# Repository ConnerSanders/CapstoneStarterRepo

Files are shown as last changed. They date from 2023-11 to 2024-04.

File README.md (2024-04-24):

# Pulse Inverted Electrolyzer

## Executive Summary

 The Pulse Inverted Electrolyzer primary goal is to boost the efficiency of the standard constant current electrolysis machine. A Standard Electrolysis system takes in constant current and turns an electrolytic solution into gasses from said solution. The  Pulse Inverted Electrolyzer will boost efficiencies in two ways. One will be by pulsing the current given to the electrodes, and the other by using constant magnetic fields to redirect ions back to the electrodes. By pulsing the current in an electrolyzer it takes advantage of two ideas happening inside the water of the system. When first fired on the electrodes will gain electrons around, and prevent current from passing through. By pulsing the current the system allows for this layer to disperse to make for more current to flow through the electrolytic solution. Also by pulsing the current, we will be able to send a burst of energy through the system instead of the constant current normally supplied. The other way the system will boost efficiency will be by using magnets placed around the housing of the cell. This will basically push the electrons closer to the electrodes and further away from the cell walls. The system will also include a way to read the power the pulse inverter will be drawing and the amount of gas being outputted, to then calculate the efficiency of the energy of the system's output versus its input. 

## Capabilities
The system will be divided into multiple systems that each have several expectations. The controller system should calculate the energy efficiency based on the flow rate of the gas output and the current draw of the pulse inverter. The safety system should any failed state go to a shutoff state. There will be a bypass for the user to be able to light the gas at the output of the gas system. The water system should automatically refill the cell with water whenever the system is too low.

## Salient Outcomes

While we did connect a pulse inverter to the cell, there were many issues with the pulse inverter tied to the resistance. The group was able to adjust to a lot of unknowns such as the pulse inverter's resistance and adapted as best as they could. Another Big outcome was the fact we had gas production from a pulsed current, as it is not common practice and with more time we could figure the best parameter of the pulse inverter to boost gas production.

## Project Demonstration & Images
[Video Demonstration](https://www.youtube.com/watch?v=DhT7RktQMQU)
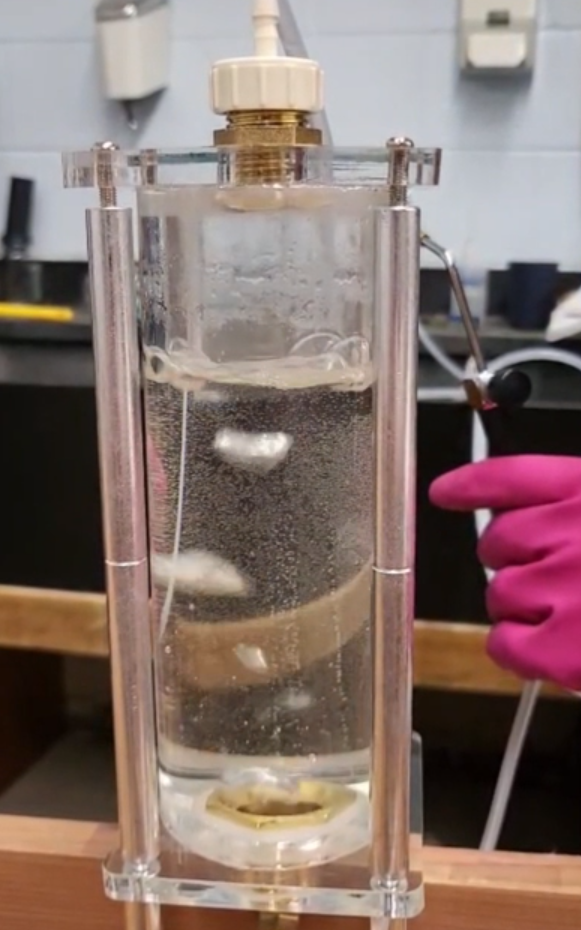
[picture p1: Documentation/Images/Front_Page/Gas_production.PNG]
<br> 
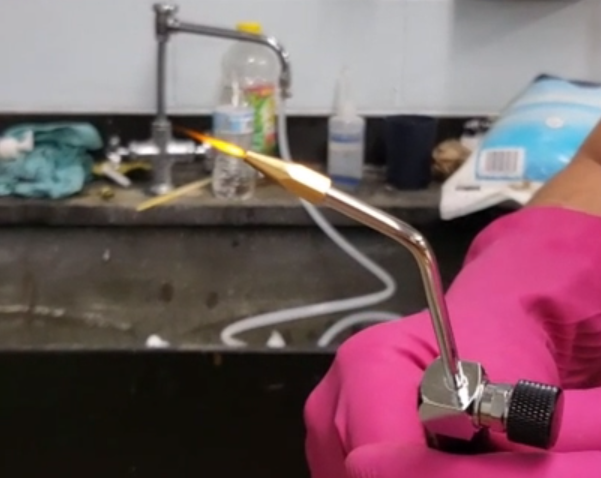
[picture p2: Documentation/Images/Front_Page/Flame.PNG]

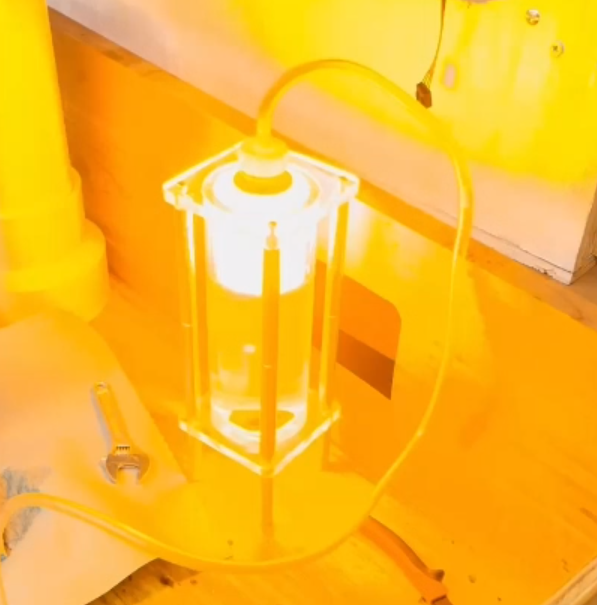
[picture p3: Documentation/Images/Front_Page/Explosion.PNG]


## About Us

### Team

**Brennan Angus**

**Matthew Beausoleil** is an Electrical Engineering student at Tennessee Technological University with a minor in Computer Science. Matthew's interests are in digital system design, telecommunications, and signal processing. Matthews's main focus in the project is the design of the water system, and ensuring that it automatically refills the water when senses it is not high enough.

**Jacob Cooper** is a Computer Engineering student at Tennessee Technological University. Jacob's interests are Circuits and Digital Based Programming. Jacob's main focus in the project is the design of the gas system and making sure there is correct ventilation and gas processing in order to create an output flame.

**Wyatt Groves** is an Electrical Engineering student at Tennessee Technological University. Wyatt's interests are Telecommunication and Signal Processing. Wyatt's main focus in the project is the design of the power system and ensuring all components receive the proper amounts of power. 

**Austin Jerrolds** is a Computer Engineering student at Tennessee Technological University. Austin's interests are Embedded Systems, Digital System Design, and software development. Austin's main focus in the project is the controller system which is responsible for the efficiency computations to measure the project's success. 

**Conner Sanders** is a Computer Engineering student at Tennessee Technological University. Conner's interests are embedded and Digital Systems. Conner also has some experience with controls and pneumatics. Conner's main focus in the project is the safety system, which cuts off power if the electrolyzer becomes unsafe.

### Faculty Supervisor
[Charles Van Neste, Phd](https://www.tntech.edu/directory/engineering/faculty/charles-van-neste.php) is an Assistant Professor at Tennessee Tech University. He received his Bachelor's, Master's, and Doctorate at Tennessee Technological University. 

### Stakeholders
The customer for the project is Dr. Van Neste for research he wishes to pursue in making a residential electrolyzer for the uses of hydrogen-powered cars. The project will be using technology develop by Dr Van Neste to see the impact it would have on the overall efficiency of the system.  

### Recognitions

The team would like to thank the ECE Department for any assistance needed in the early stages of design. We would especially like to thank **Jesse Roberts** for helping the team when Dr. Van Neste was busy with other work. 

## Repo Organization

### [Reports](/Reports)

The [Project Proposal](/Reports/Proposal/Project_Proposal-V2.pdf) report addresses key questions about the project. It states exactly what the problem is and what the solution plans to achieve. 

The [Conceptual Design and Planning](/Reports/Conceptual%20Design/Conceptual_DesignV2.pdf) report provides all specifications and constraints the project must follow. This includes standards and regulations that must be followed.

The [Experimentation](/Reports/Experimentation/Experimentation.md) report shows the experimentation done by the team to verify the project's constraints and measures of success.

The [Poster](/Reports/Poster/Capstone_Final_Presentation_Poster.pdf) is a visual summary of the project that is presented at the Senior Design Expo.

The [Final Presentation](/Reports/Final%20Presentation/Capstone%20Final%20Presentation.pdf) includes the final report/presentation done by the team to summarize the project's progress.

The [Lessons Learned](/Reports/Lessons%20Learned/Lessons%20Learned.md) files show all lessons learned throughout the process. It includes lessons in team communication, project management, and technical knowledge.

### [Documentation](/Documentation)

All documentation is included in the above folder. Folders for the files including schematics and images are included in their respective folders. All files related to a specific signoff are then in a subfolder labelled appropriately.

Documentation includes all schematics, images, models, and designs used in the project. 

[Signoffs](/Documentation/Ss) folder houses all approved detail designs. These designs are for each subsystem and show all constraints. The signoffs should convince the reader that all constraints are met as well as link to all other relevant documentation in their respective folders. These signoffs should also link any relevant software.

The [Meeting Minutes](/Documentation/Meeting%20Minutes) folder contains dated minutes for all team meetings. This allows the reader to analyze current and previous progress in a time-based manner. 

### Software
All software will be located in this directory. For each specific problem or system, a folder will be created that contains all relevant code along with a readme that explains the installation, compiling, and execution of the code.

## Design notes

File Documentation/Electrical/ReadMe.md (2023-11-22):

## Electrical Schematics Included 
1. Electrolysis System Pulse Inverter
2. Controller System Sensors and Microcontroller
3. Water System Valve
4. Power System Wiring
5. Safety System Wiring

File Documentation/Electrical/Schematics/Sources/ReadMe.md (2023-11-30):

## DWG Files of Included Electrical Schematics
1. Controller System Sensors and Microcontroller
2. Water System Valve
3. Power System Wiring
4. Safety System Wiring
5. Power Subsystem

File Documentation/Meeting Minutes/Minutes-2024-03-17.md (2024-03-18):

Week 9 - 0 Minute Session

Attendance: None due to Spring Break

Notes: Acommplishing Minimal Functionality was a success.

Group Decisions: We need to add the pulse inverter and other sensors, along with maintaining functionality.

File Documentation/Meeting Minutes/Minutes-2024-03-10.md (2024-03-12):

Week 8 - 50 minute session

Attendance: Brennan Angus ,Matthew Beausoleil, Jacob Cooper, Wyatt Groves, Austin Jerrolds, Conner Sanders

Notes: Acommplishing Minimal Functionality was a success. Dr. Van Neste witnessed our electrolysis and flame generated.

Group Decisions: We need to add the pulse inverter and other sensors, along with maintaining functionality.

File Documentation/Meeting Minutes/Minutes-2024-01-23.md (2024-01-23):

5/6 members; missing Jacob Cooper - notice was givin beforehand

Discussed current standings, collected all ordered materials

Decisions: Begin building soon

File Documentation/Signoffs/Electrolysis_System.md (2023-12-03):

# Electrolysis System
## Function of the System
The role of the system is to implement the process necessary for generating the hydrogen and oxygen gases. The system consists of a pre-made electrolytic cell, a pulse inverter, a rectifier, an auxiliary capacitor, and permanent magnets. The pulse inverter will be the power source of the system, and the rectifier will be used on the output of the pulse inverter to ensure that the polarity of the input power is consistent. The magnets will be used to boost the system's efficiency. The auxiliary capacitor will be used for manipulating pulse duration.

## Constraints
| No. | Constraints | Origin |
| --- | --- | --- |
| 1 | The material of the electrolytic cell housing shall not be reactive with sodium hydroxide. | Design Constraint |
| 2 | The material of the electrolytic cell should be transparent or translucent. | Design Constraint |
| 3 | The system shall include a pulse generator and permanent magnets to boost efficiency. | Design Constraint |
| 4 | The pulse generator’s output should be rectified. | Design Constraint |
| 5 | The electrolysis cell shall have no permanent storage of gases. | OSHA Standards 1910.103 and 1910.104 |
| 6 | Pulse inverter must be able to be shut off within two clock cycles by the safety system. | Design Constraint |
| 7 | Safety system must shut off the system when the cell's pressure is at 15 PSI. | Design Constraint |

<sup>1</sup>
The material of the cell not being reactive with sodium hydroxide is essential both for functionality and safety, given that sodium hydroxide will be part of the solution housed in the cell.

<sup>2</sup>
This is a preference decided by the team.

<sup>3</sup>
The pulse generator will be the system's power source, and its frequency and amplitude will be manipulated for optimizing efficiency. The magnets will serve to bias the ions in the solution toward the electrodes in order to increase interaction and boost efficiency.

<sup>4</sup>
The rectification of the pulse generator's output, while not essential to the function of the system as it is being designed, is prefered as it makes possible future development more approachable. The direct purpose of the rectification is that it keeps the location of hydrogen and oxygen gas generation seperate so that, if and when necessary, the gases can more easily be isolated from one another.

<sup>5</sup>
Hydrogen and oxygen gas will not be stored in the cell as pressurized storage of the gases results in a combustible system.

<sup>6</sup>
This will prevent any excessive delays that may be a safety concern.

<sup>7</sup>
While the pressure capacity of the cell being ordered is unknown, 15 PSI was chosen as a limit given the expectation that pressure should not increase by any substantial amount. With this, the system will be shut off when pressure starts to build,  with 15 PSI being chosen as a safe limit where any fault in the system will not be a safety concern, regardless of the cell's capacity.

## Buildable Schematic
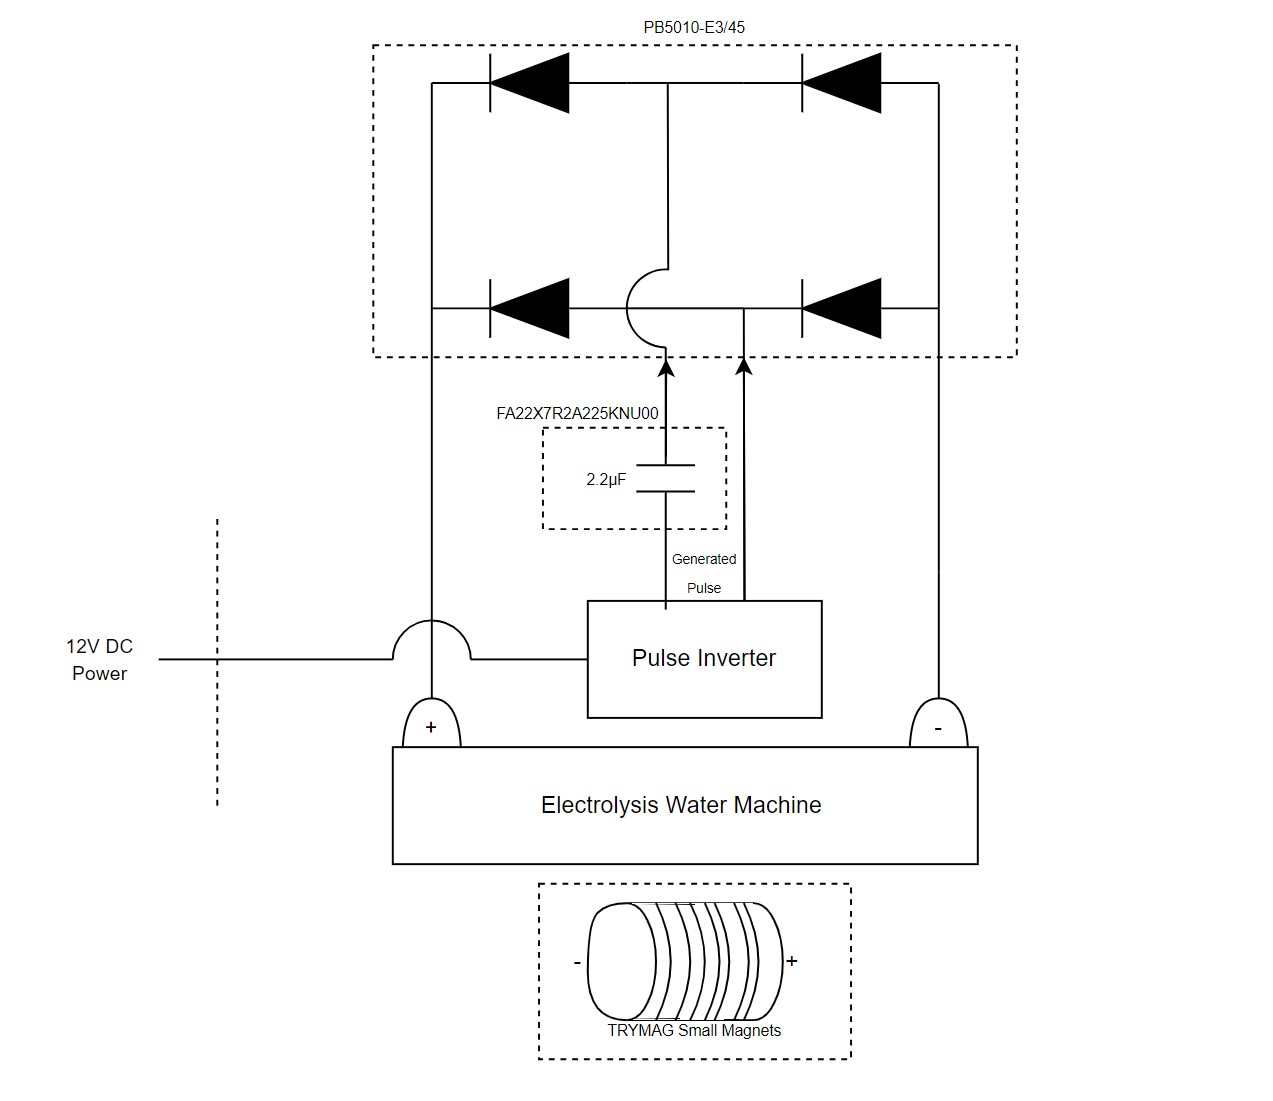
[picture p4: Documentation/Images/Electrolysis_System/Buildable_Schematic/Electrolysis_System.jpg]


## Analysis
### Cell
The material of the cell to be ordered is appropriate as it is not reactive with sodium hydroxide. This is known because the instruction manual for the product can be quoted as instructing users to use 3 grams of sodium hydroxide per 600 mL of water. It is also large enough that it can hold the amount of water necessary for producing a constant flame. With gas storage not being used for the project, the pressure capacity of the cell is irrelevant, and the safety system will be used to automate pressure limitation in cases where a system malfunction causes pressure to start to build. The cell has one hole through which water comes in and gas escapes, meaning that it will never be fully shut for pressure to build. While the cell itself isn't transparent or translucent, enough components of the whoe unit being ordered allows for higher convenience than a totally opaque cell.

### Optimization Tools
The pulse inverter to be used is sufficient as it is made to function as an AC source running at 250 Hz (500 Hz after rectification). The TRYMAG magnets to be used as they are small and therefore easily manipulable. The magnets coming in a pack of 150 ensures that there will be plenty and that magnets will always be available when replacement is necessary. The magnets will be attached to the electrolytic cell by means of hot gluing them across the cell holding the electrodes. Neither the pulse inverter nor the magnets are extremely confined with stringent specifications as the optimization they contribute (and their traits which boost it) are not yet known.

### Rectification
The rectifier selected is appropriate for the system as its maximum repetitive peak voltage is 1000 V and the average rectified forward current is 50 A. These limits are high enough that the system can function without exceeding them, given that the pulse generated by the pulse inverter will have an amplitude of roughly 12 V. The rectifiers chosen are also convenient due to them having screw holes which make them easy to mount. The ripple voltage produced by the rectifier is not an issue, as the only value being considered is the amplitude of the output pulses.

### Auxiliary Capacitor
The auxiliary capacitor is used for manipulating pulse widths that are seen by the electrolysis water machine. The FA22X7R2A225KNU00 capacitor was selected because it is ceramic as opposed to electrolytic, and its ratings indicate that it is capable of handling voltages greater than those shown across Caux in simulation. It being ceramic is important for the bipolar voltage (this disqualifies electrolytic capacitors). The FA22X7R2A225KNU00, in particular, was selected because its legs make it practical and its rated voltage of 50 V is more than enough to handle the voltages put across it by the rest of the system.

## BOM
| Device | Quantity | Price per Unit | Total Cost |
| --- | --- | --- | --- |
| Electrolysis Water Machine with Spray-Gun | 1 | $93.99 | $93.99 |
| TRYMAG Small Magnets 150Pcs, 12x2mm Neodymium Magnets | 1 | $16.19 | $16.19 |
| Pulse Inverter | 1 | NA | NA |
| KBPC5010 Bridge Rectifier | 5 | $1.80 | $8.99 |
| FA22X7R2A225KNU00 Capacitor | 1 | $1.73 | $1.73 |
| Total | | | NA |

## References
Tap Water Resistivity: https://www.researchgate.net/figure/Resistivity-of-tap-water-with-different-amounts-of-salt-added_tbl2_352785351

Electrolysis Water Machine: https://www.ebay.com/itm/174776123639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

TRYMAG Small Magnets: https://www.amazon.com/TRYMAG-Different-Neodymium-Refrigerator-Whiteboard/dp/B0CHVPD4K8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

Bridgold 5pcs KBPC5010 Bridge Rectifier: https://www.amazon.com/Bridgold-KBPC5010-Rectifier-Electronic-Silicon/dp/B07MQ65HLB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

Auxiliary Capacitor: https://www.mouser.com/ProductDetail/TDK/FA22X7R2A225KNU00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

Electrolysis Water Machine Instruction Manual:



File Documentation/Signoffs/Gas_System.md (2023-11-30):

# Gas System
## Function of the system
The gas system plays an essential role in facilitating the electrolysis process, particularly in the context of collecting and handling the gases produced during electrolysis. This will be done with two arrestors and a torch to create a flame.

## Constraints
| No. | Constraints | Origin |
| --- | --- | --- |
| 1| The presence of corrosive gases or electrolytes in the system shall be avoided. | Design Constraint |**********************
| 2| The controlling and managing of the pressure of gases shall be used within the system. | Design Constraint |
| 3| The temperature shall be monitored in order to make sure the gas temperature is not affected.					| Design Constraint |
|	4| The gas system shall be designed to handle the expected gas production capacity.		| Design Constraint |
| 5| Maintenance and Monitoring shall be constant in the gas system to prevent unexpected breakdowns. | Ethical Constraint|

<sup>1</sup>
The gas system shall facilitate the safe handling and storage of the gases produced during electrolysis.

<sup>2</sup>
The gas system shall contribute to the overall control and optimization of the electrolysis process.

<sup>3</sup>
The gas system shall be equipped with components that aid in the separation and purification of the gases.

## Buildable Schematic

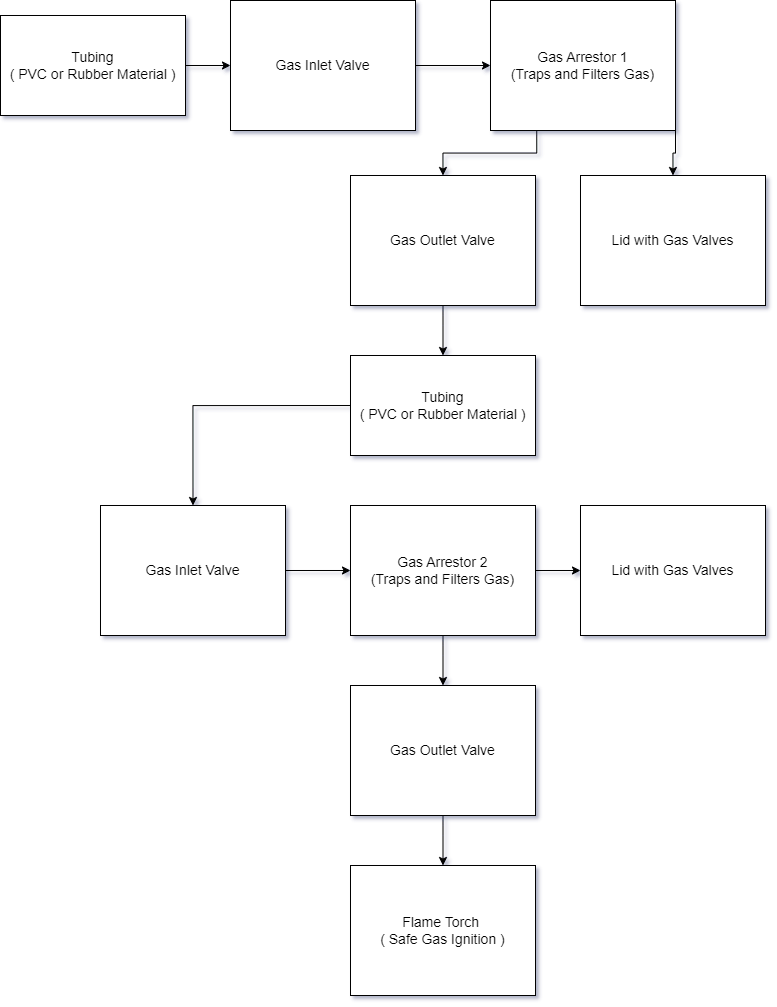
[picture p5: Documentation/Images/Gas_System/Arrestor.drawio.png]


## Analysis

#### Gas Arrestor

In an electrolysis system, a gas arrestor, or gas trap, is a device used to capture and separate unwanted or hazardous gases produced during the electrolysis process. These gases may include volatile byproducts, impurities, or any potentially dangerous gases that need to be removed or trapped before they can escape into the surrounding environment. The gas arrestor works through a series of mechanisms to ensure the safe and efficient operation of the electrolysis system.

#### Electrolysis Flame Torch

The flame torch in this gas arrestor system serves a crucial role in ensuring the safe ignition of gases. Its primary function is to provide a controlled flame for initiating the combustion process. Designed with user safety in mind, the torch acts as a reliable source for igniting gases without the risk of unwanted combustion. Its integration into the system enhances the overall safety and efficiency of gas handling during the electrolysis process.

#### Gas Inlet and Outlet Valves

The gas inlet and outlet valves are pivotal components that regulate the flow of gases within the gas arrestor system. Configured for airtight sealing on the transparent container's lid, these valves facilitate controlled entry and exit of gases. The use of three valves allows for precise control over gas flow, ensuring safety and operational efficiency. Their construction from durable materials such as PVC or rubber enhances resistance to the handled gases, reducing the risk of leaks and ensuring a secure containment environment.

#### Tubing

The tubing in the gas arrestor system is a critical conduit connecting the gas inlet valve to the absorbent material at the bottom of the container. Constructed from PVC or rubber, the tubing is chosen for its resistance to the specific gases being handled. Its 1/4" diameter strikes a balance between efficient gas flow and controlled passage. The tubing's secure attachment to the gas inlet valve and placement within the container ensures a well-directed flow of gases through the absorbent material, optimizing the absorption and filtration process for enhanced safety and performance.

## BOM
| Device | Quantity | Price per Unit ($) | Total Cost ($) |
| --- | --- | --- | --- |
|Transparent Container|1|9.99|9.99|
|Gas Inlet and Outlet Valves|3|15.38|46.14|
|Silicon Sealant|1|9.99|9.99|
|1/4" Vinyl Hose 25' long|2|9.28|18.56|
|Searer Torch|1|11.00|11.00|
|Valve Box Lid|2|30.87|61.74|

## References

[1] https://www.energy.gov/eere/fuelcells/hydrogen-production-electrolysis
[2] https://www.sciencedirect.com/topics/engineering/power-to-gas-system
[3] https://www.accelerazero.com/news/what-is-an-electrolyzer-and-what-is-it-used-for
[4] https://www.amazon.com/Gas-Tube-Arrestors/b?ie=UTF8&node=306525011
[5] https://www.sciencemadness.org/talk/viewthread.php?tid=14167
[6] https://hackaday.com/2013/10/11/diy-hho-mini-torch/
[7] https://sciencing.com/make-hydrogen-torch-6456097.html
[8] https://www.homedepot.com/p/Flame-King-Searer-Torch-Attachment-Tip-for-Propane-and-Butane-Torch-YSN-SEARER-01/315298340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

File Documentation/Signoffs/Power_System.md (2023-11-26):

# Power Subsystem

## Function of the Subsystem

This subsystem's purpose is to allow power supplied from a wall outlet to be used in our device.

## Constraints

| No. | Constraints | Origin |
| --- | --- | --- |
| 1 | The system shall convert wall AC Voltage to DC voltage | Design Constraint |
| 2 | The system shall comply with NFPA 70, in reference to all wiring and power consumption | Design Constraint/ NFPA 70 |
| 3 | The subsystems shall not have fluctuations in voltage of greater or less than 10 volts compared to the rated voltage  | Design Constraints |
| 4 | The system shall be able to power multpile different devices with different rated voltages | Design Constraint |
| 5 | The system shall be able to supply 5 VDC | Design Constraint |
| 6 | The system shall be able to supply 12 VDC | Design Constraint |
| 7 | The system shall have no dangerous exposed wires and shall be grounded as needed | OSHA 1910.304 - 305 and IEC 60950-1 Safety Standards |

<sup>1</sup> All components will be powered with DC inputs, ensuring the system is more easily buildable, and more consistent between subsystems.

<sup>2</sup> While not necessarily a contraint, it is good practice to be capable of supplying 1.2x more power than is expected to be drawn. This will account for some unexpected spikes in power draw that may otherwise cause a system failure.

| Device | Voltage |
| --- | --- |
| Pulse Inverter (Capacitor Input) | 12 V |
| Water Flow Valve | 12 V |
| Water Flow Sensor | 12 V |
| Pressure Sensor | 12 V |
| Temperature Sensor |  5 V |
| UV Sensor | 5 V |
| Power Sensor |  5 V |
| Gas Flow Sensor | 5 V |

The above table lists the rated voltages of each device.

<sup>3</sup> Different subsystems require different voltages. This will be accomplished by having 1 power supply supplying 12 VDC that is stepped down to 5 VDC using a buck converter.

<sup>4</sup>  A typical wall outlet will be used to power the device to avoid the issue of nonstandardized outlets needed to be present in the home of the user.

## Buildable schematic 

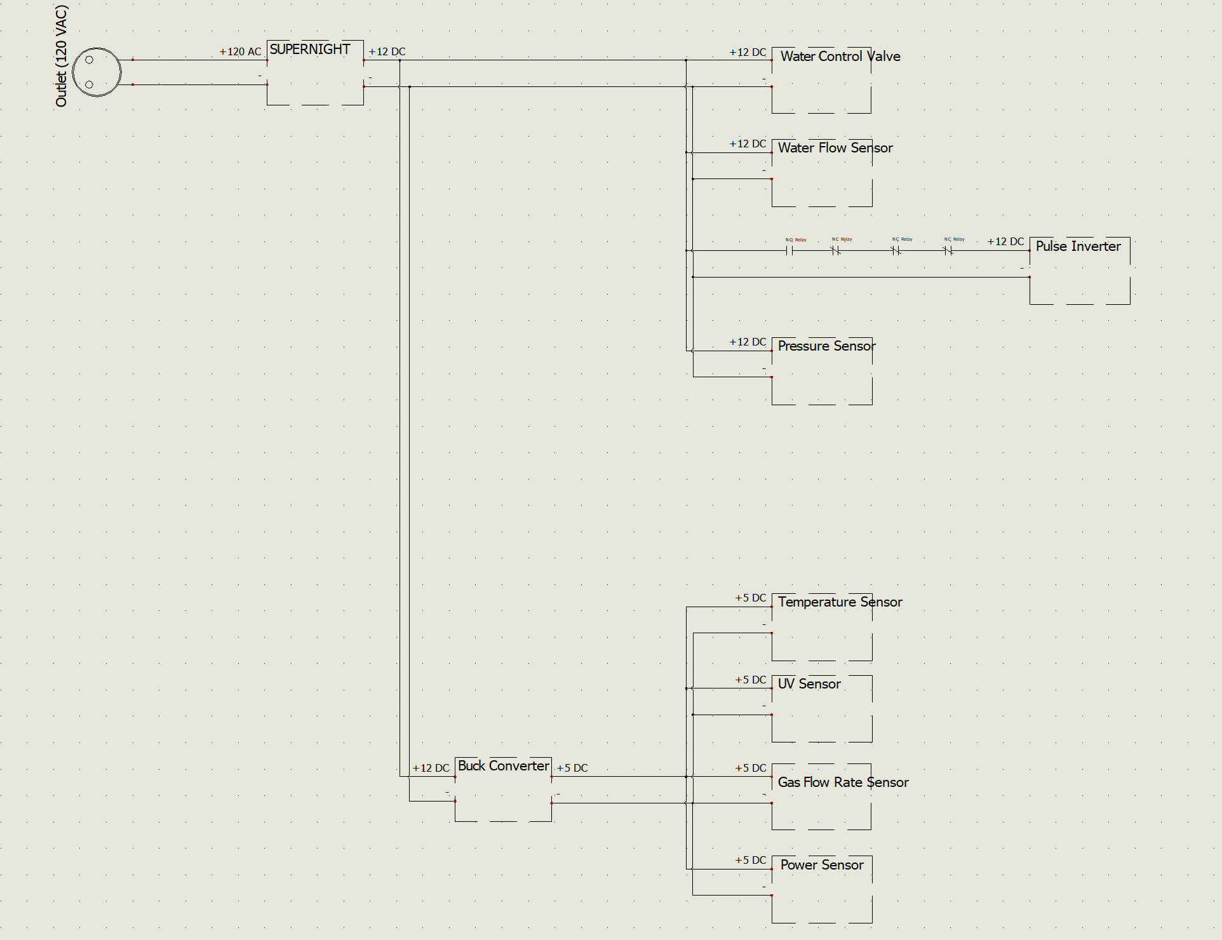
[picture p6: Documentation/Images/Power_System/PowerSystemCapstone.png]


*Figure 1. Power Subsystem buildable schematic.*

<sup>5</sup>  The relays shown connected to the pulse inverter have the labels "NO" and "NC." "NO" stands for "Normally Open." "NC" stands for "Normally Closed."

## Analysis

| DEVICE | Power |Total Power |
| --- | --- | --- |
| Pulse Inverter | 50 W | | 
| Water Flow Valve | 18 W | | 
| Water Level Sensor | 60 mW | | 
| Pressure Sensor | 96 W | | 
| Temperature Sensor | 50 mW | | 
| UV Sensor |  680 nW | | 
| Power Sensor | 1.55 mW | | 
| Gas Flow Sensor | 19 mW | |
| | | 164 W |

Pulse Inverter

The pulse inverter will be powered by 12 VDC and will have an average power draw of 50 W. This means the average current draw is
~~~math
I_{Pulse Inverter} = P/V = (50W)/(12V) = 4.167A
~~~

Water Flow Valve

The water flow valve will be powered by 12 VDC and will have a power draw of 18 W. This means the current draw is
~~~math
I_{Water Flow Valve} = P/V = (18W)/(12V) = 1.5A
~~~

Water Level Sensor

The water level sensor will be powered by 12 VDC and will have a power draw of 60 mW. This means the current draw is
~~~math
I_{Pulse Inverter} = P/V = (60mW)/(12V) = 5mA
~~~

Pressure Sensor

The pressure sensor will be powered by 12 VDC and will have a power draw of 96 W. This means the current draw is
~~~math
I_{Pulse Inverter} = P/V = (96W)/(12V) = 8A
~~~

Temperature Sensor

The temperature sensor will be powered by 5 VDC and will have a power draw of 50 mW. This means the current draw is
~~~math
I_{Pulse Inverter} = P/V = (50mW)/(5V) = 10mA
~~~

UV Sensor

The water level sensor will be powered by 12 VDC and will have a power draw of 680 nW. This means the current draw is
~~~math
I_{Pulse Inverter} = P/V = (680nW)/(12V) = 136nA
~~~

Power Sensor

The power sensor will be powered by 5 VDC and will have a power draw of 1.55 mW. This means the current draw is
~~~math
I_{Power Sensor} = P/V = (1.55mW)/(5V) = 310μA
~~~

Gas Flow Sensor

The gas flow sensor will be powered by 5VDC and will have a power draw of 19 mW. This means the current draw is
~~~math
I_{Gas Flow Snesor} = P/V = (19mW)/(5V) = 3.8mA
~~~

The 12 VDC will be supplied by the SUPERNIGHT 110~240 VAC to 12 VDC.

The voltage regulation from 12 V to 5 V will be done by the Weewooday Direct Current Converter.

The supply will pull from a standard wall outlet (120 VAC) and will be wired into a 12 VDC power supply. The power supply will then be split into the buck converter circuit (which feeds the safety subsystem(s)), the water control circuit, and the pulse inverter circuit.

 The below equation was used for the power calculations for all devices.
~~~math
P = VI
~~~

### Power Supply

As mentioned previously, the SUPERNIGHT power supply will be used. This can support up to 30 A, which sould be more than enough to reliably power the entire system.

### Input

The input for this subsystem is the 120 VAC coming from the wall outlet.

### Output

There are two outputs for the system. The first output the one from the power supply, which is the 12 VDC. The second output is the one from the buck converter, which is the 5 VDC.

### Relay Coil

There will be a total of four relay coils. Three of the relays will be normally closed, and one will be normally open. These will connect to the various safety devices, all controlling the input to the pulse inverter. The relays will be connected to the pulse inverter because if they are ever open, then there is likely some sort of error or malfunction. This will mean that the pulse inverter is shut off, ensuring that no more gas is generated.

## BOM
| DEVICE | Quantity | Price Per Unit | Total Price |
| --- | --- | --- | --- |
| SUPERNIGHT | 1 | $18.98 | $18.98 |
| Weewooday | 1 | $14.99 | $14.99 |

## References
[1] SUPERNIGHT 12V 30A Switching Power Supply, 110-240 Volt AC to DC 360W Universal Regulated Switching Transformer Adapter Driver for 3D Printer, CCTV, Radio, LED Strip Lights,Computer Project, https://www.amazon.com/SUPERNIGHT-Switching-Universal-Regulated-Transformer/dp/B01LATMSGS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

[2] 12V to 5V DC Converter Car Power Voltage, Waterproof DC 6.3-22V 12V Step Down to DC 5V 3A 15W Voltage Regulator Buck Converter Power Supply Step-Down Module Compatible with Vehicle Car Truck Volt, https://www.amazon.com/Converter-Voltage-Waterproof-Regulator-Step-Down/dp/B07Y2V1F8V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

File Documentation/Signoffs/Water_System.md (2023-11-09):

# Water System
## Function of the system
The goal of this system is to make sure the that the water in the electrolytic cell never drops below 2/3 of the cell capactity. This will be done with a non-contact water level sensor placed 2/3  the height of the cell housing. This ensure that the cell water level stay to the recommended level by the manufacturer of the cell. When the sensor is high than the water control valve needs to be shutoff, so the signal out the sensor will need to be inverted.

## Constraints
| No. | Constraints | Origin |
| --- | --- | --- |
| 1| The water in the cell shall automatically refill when below 2/3 the cells capacity . | Design Constraint | **********************
| 2| The water level sensor shall be affixed to the outside of the cell. | Design Constraint |
| 3| The water system shall have a hole below the water level					 | Design Constraint |
|	4| The water system fittings will use non-corrosive materials for fittings			 | Design Constraint |
| 5| The water system shall prevent backwards flow of water. | Ethical Constraint|

<sup>1</sup>
The electroyltic cell needs to have a certain amount of water at all times to keep efficiency up.

<sup>2</sup>
This is due to the fact that the cell does not have enough room in the cell to house the sensors.

<sup>3</sup>
The system does not want to introduce another way for the gas to leave the system. By submerging the water inlet for the cell the gas will rise to the top of the cell and not hang in the water inlet tube.

<sup>4</sup>
The system needs to run with out issues as long as possible. The fittings need to be as corrosive resistant as possible to help keep the longevity of the cell.

<sup>5</sup>
This is to ensure that the water supply would not get contaminated by what is in the cell.

## Buildable Schematic

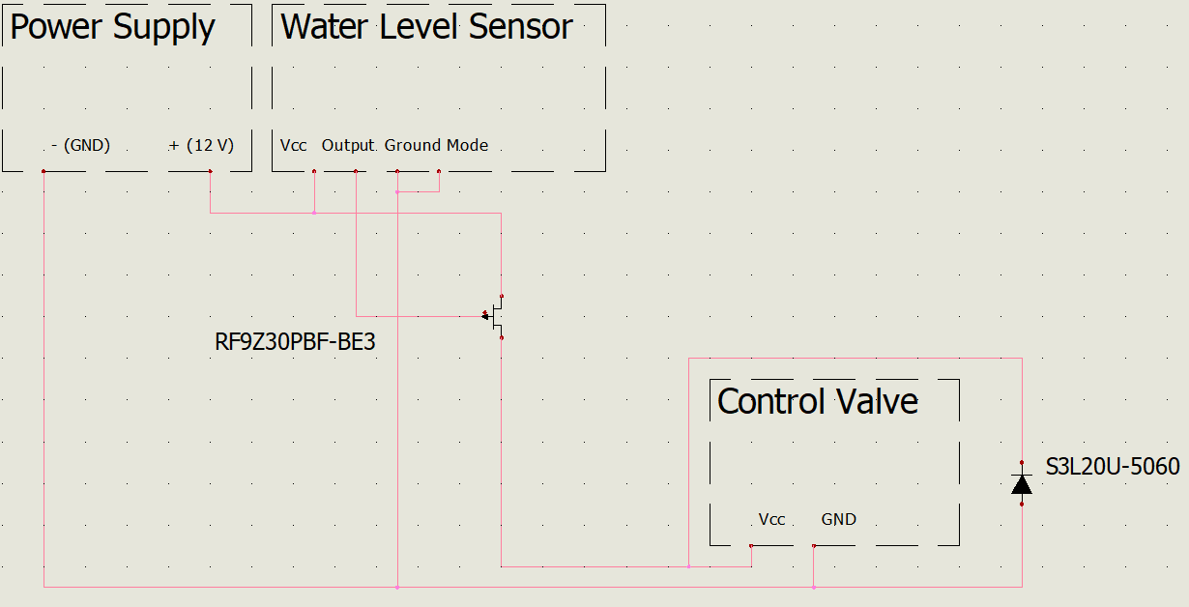
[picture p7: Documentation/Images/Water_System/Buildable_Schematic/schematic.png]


## Analysis

#### Non-Contact Capacitive Water Level Sensor

The sensor uses its own capacitance and parasitic capacitance of the water to determent when the water level has reached a fixed point in front of the sensor. The sensor will be mounted on the outside. When the sensor goes high when the water level is at the 2/3 mark of the cell. This means the signal needs to be inverted when controlling the solenoid of the control valve. When the water level is high the sensor will make the gate voltage the same as the source voltage keep the PFET transistor close. When the sensor is low, the gate will be lower than the source making the PFET transistor open and allowing water to fill up. When the transistor goes from the on to off state the diode allows current to flow back in to the soleniod and disspate and prevent the any damage to the transistor.

#### Electrically Accuated Control Valve

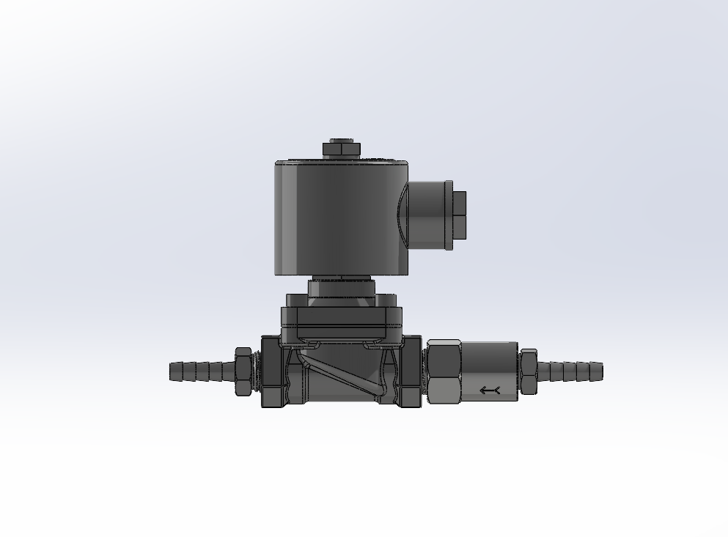
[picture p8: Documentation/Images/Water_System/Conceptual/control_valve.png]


As shown in the figure above, the control valve will have several fittings to allow for hose to be connected from various parts of the whole system. The inlet of the valve has is a barbed 1/4" to 3/8" NPT Male fitting to than go to the check valve. The check valve will ensure that the system water does contaminate the city water supply. The control valve outlet than goes to the same fitting as the inlet. This will allow for cheap 1/4 vinyl tubing to be bought in bulk, so there is no need to run hard plumbing to fill the system up. The connection will be a series of adatapers frome a faucet to a 1/4" Barb

## BOM
| Device | Quantity | Price per Unit ($) | Total Cost ($) |
| --- | --- | --- | --- |
|Tank Fitting|1|10.23|10.23|
|3/8" Male to Barbed Hose Fitting|2|15.38|46.14|
|Faucet to Garden Hose adapter|1|9.98|9.98|
|Garden Hose to National Pipe Thread Adapter|1|8.99|8.99|
|3/4' Barbed Hose Fitting|1|10.35|10.35|
|Worm-Drive Clamp|1|10.52|10.52|
|1/4" Vinyl Hose 25' long|2|9.28|18.56|
|Non-Contact Capacitive Water Level Sensor|2| 9.94|19.88|
|Electric Brass Solenoid Valve|1|44.95|44.95|
|200 Vrm Diode|2|2.24|4.48|
|60 V P-FET| 2| 2.52| 6.02|
| ------ | -------- | -------------- | ---------- |
|Total|||190.20|

## References

[1] https://www.mcmaster.com/products/flow-valves/check-valves~/body-material~brass-2/threaded-check-valves-10/pipe-size~3-8/

[2] https://www.electricsolenoidvalves.com/3-8-12v-dc-electric-brass-solenoid-valve/#description

[3][ https://www.amazon.com/Waterproof-Contact-Liquid-Sensor-Signal/dp/B0B7W9QYRX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](https://www.amazon.com/dp/B074PVF341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)https://www.amazon.com/dp/B074PVF341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

[4] https://www.mcmaster.com/5346K95/

[5] https://www.mcmaster.com/9151K265/

[6] https://www.mcmaster.com/1075T23/

[7] https://www.mcmaster.com/5388K14/

[8] https://www.lowes.com/pd/EZ-FLO-1-4-in-Inner-Diameter-x-25-ft-Polyethylene-Tubing/1000180497

[9] https://www.lowes.com/pd/Danco-3-4-in-GHTF-x-55-64-in-27M-Chrome-Dishwasher-Aerator-Adapter/3647054

[10] https://www.mcmaster.com/5346K46/

[11] https://www.amazon.com/Adapter-Connector-Fitting-Fittings-Connect/dp/B087GKPMVG/ref=pd_bxgy_sccl_2
/138-4857020-0099853?pd_rd_w=cIsdc&content-id=amzn1.sym.21b577c4-6435-4581-8b53-49da41e27328&pf_rd_p=21b577c4-6435-4581-8b53-49da41e27328&pf_rd_r=MQHGMHZ183HCK92E62MY&pd_rd_wg=w7sxm&pd_rd_r=3093a3d2-2d17-458e-a486-307ecc96fd8c&pd_rd_i=B087GKPMVG&th=1]

[12] https://www.mcmaster.com/5346K46/

[13] https://www.mouser.com/ProductDetail/Vishay-Siliconix/IRF9Z30PBF-BE3?qs=7MVldsJ5UazmpG%252BNXOVzGA%3D%3D

[14] https://www.mouser.com/ProductDetail/Shindengen/S3L20U-5060?qs=OSm%2FIAICcjaotcbGQrz8jA%3D%3D

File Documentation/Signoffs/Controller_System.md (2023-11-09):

# Controller System
## Function of the system

The goal of the system is to read the sensor values, compute the efficiency of the electrolyzer and output the rating to a display. The subsystem consists of a microcontroller that will perform the calculations, an energy metering IC to determine how much power the electrolyzer is using, and a flow rate sensor to determine gas content. The sensor readings and efficiency rating will then be output to a serial terminal where it can be viewed.
##### Psuedo Code Flowchart
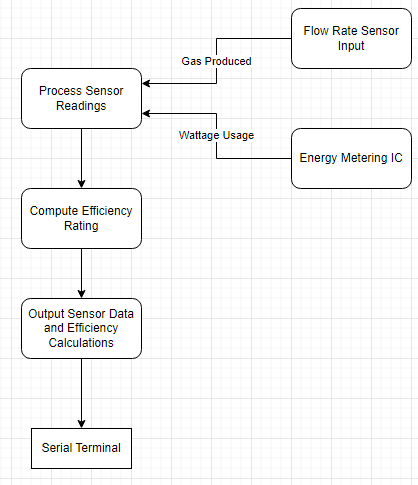
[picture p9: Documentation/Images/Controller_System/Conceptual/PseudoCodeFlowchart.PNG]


## Constraints
| No. | Constraints | Origin |
| --- | --- | --- |
| 1 | Shall accurately measure the electrical efficiency of the electrolyzer | Design Constraint |
| 2 | Shall use sensors to measure gas output and electrical input | Design Constraint |
| 3 | Shall output efficiency rating and sensor readings to a serial port | Design Constraint | 
| 4 | Display output shall be easy to read and simplistic. | Ethics Constraint |

<sup>1</sup> Success of the subsystem requires that it is able to compute an efficiency rating of the electrolyzer. The computations are there to confirm if the methods of increasing the efficiency of electrolysis are successful.

<sup>2</sup> To compute an efficiency rating there will need to be a way to measure the energy input and output of the electrolyzer.

<sup>3</sup> For a user to view the efficiency rating and necessary sensor data there must be a way to view it. Using the serial port on a microcontroller the information can be viewed through an external device that can use a serial terminal.

<sup>4</sup> In order for the system to be accessible to the most amount of people the interface needs to be able to be easily understood.

## Buildable Schematic
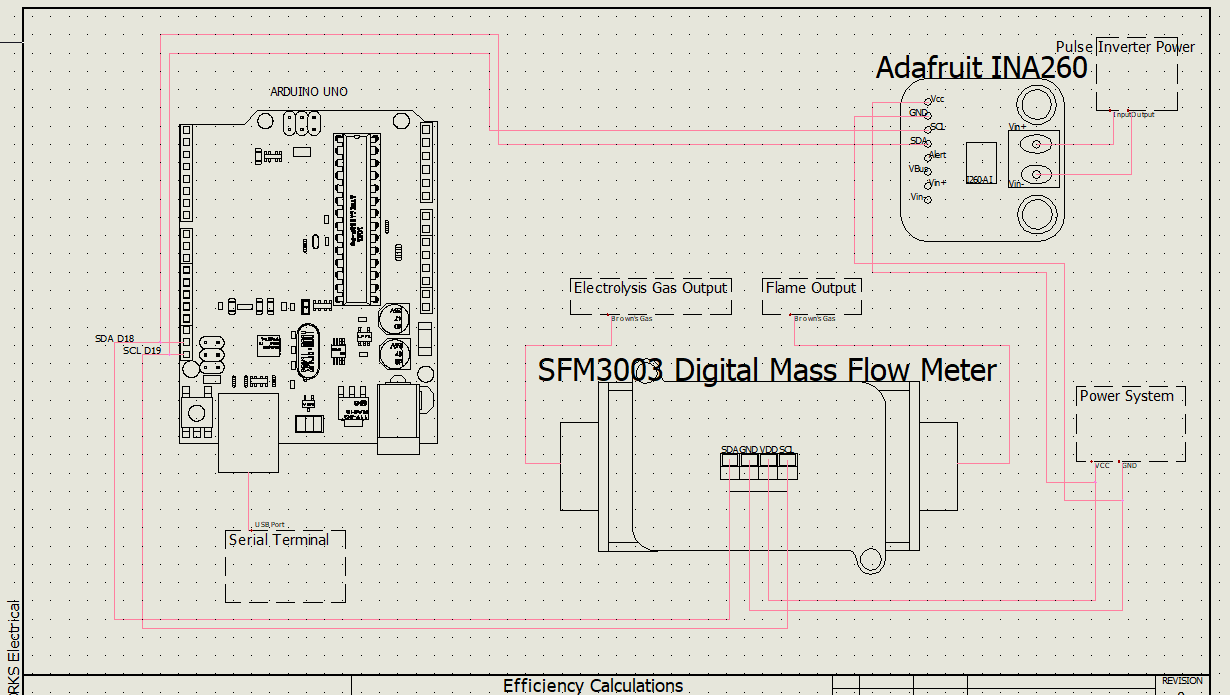
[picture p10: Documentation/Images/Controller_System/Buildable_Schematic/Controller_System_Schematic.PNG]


The above image showcases the full buildable schematic of the controller system. The schematic shows the required sensors as well as the way they connect to the other systems.

## Analysis

#### Input
The system will take inputs from the power system on how much power the system is using and from the electrolysis cell on how much gas the system is producing. 
#### Output
The system will output sensor data from the INA260 and SFM3003, as well as the calculations performed by the microcontroller.
#### INA260
The microcontroller will take input from the INA260. This sensor is responsible for determining how much power the system is using. The microcontroller will output this data to the serial terminal. [1]
#### SFM3003
The microcontroller will take input from the SFM3003. This is a sensor that will measure the flow rate of Brown's gas exiting the electrolysis cell, using the input from the sensor, the microcontroller can calculate how much gas is being generated. [2]
#### Arduino Uno Rev3
The Arduino Uno will be responsible for the sensor processing and efficiency calculations required for the system's success. [3]
#### Communications
The sensors and microcontroller will communicate through a communications protocol known as I^2C. This protocol is a bus interface connection that allows for multiple peripherals to communicate. The sensors and microcontroller will all be connected to D18 for the SDA port and D19 for the SCL port. [4]
#### Serial Terminal
The serial terminal will be how the microcontroller is able to communicate with a user. The terminal can be accessed using a laptop through Arduino's IDE in the Serial Monitor Tool. The Arduino IDE can be accessed with a Windows 10, Linux, or macOS operating system. [5]

## BOM
| Device | Quantity | Total Cost |
| --- | --- | --- |
| Arduino Uno Rev3 | 1 | $27.60 |
| Flowrate Sensor SFM3003 | 1 | $118.17 |
| Adafruit INA260 | 1 | $9.95  |

## References
[1] INA260 Precision Digital Current and Power Monitor, https://www.ti.com/lit/ds/symlink/ina260.pdf (accessed Oct. 29, 2023). 

[2] GF DS SFM3003-300 D3 - Mouser Electronics, https://www.mouser.com/datasheet/2/682/Sensirion_Mass_Flow_Meters_SFM3003_Datasheet-2492120.pdf (accessed Oct. 29, 2023). 

[3] Arduino® Uno R3, https://docs.arduino.cc/resources/datasheets/A000066-datasheet.pdf (accessed Oct. 29, 2023). 

[4] I2C - SparkFun Learn, https://learn.sparkfun.com/tutorials/i2c/all (accessed Oct. 28, 2023). 

[5] “Software,” Arduino, https://www.arduino.cc/en/software (accessed Oct. 28, 2023). 

[6] Adafruit INA260 Current, Voltage, Power Sensor Breakout, https://cdn-learn.adafruit.com/downloads/pdf/adafruit-ina260-current-voltage-power-sensor-breakout.pdf (accessed Oct. 29, 2023).

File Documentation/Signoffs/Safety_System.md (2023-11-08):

# Safety System
## Function of the system
This system will shut-off power to the pulse inverter if the system becomes unsafe, halting any gas production. The system consists of a flame detector, pressure sensor, temperature sensor, and an emergency stop button. Normally open relay contacts will be connected to all components previously mentioned. In the event that any of these contacts are closed, the relay coil will be de-energised, and power to the pulse inverter will be disconnected.

## Constraints
| No. | Constraints | Origin |
| --- | --- | --- |
| 1 | Shall contain an emergency-stop button | NFPA 79 |
| 2 | Shall shutoff if pressure and temperature approach ignition conditions of Brown's gas | Design Constraint | 
| 3 | System monitors must be designed with redundancies | Design Constraint |
| 4 | System shall not produce gas unless there is a flame present | Design Constraint

<sup>1</sup>
NFPA 79 states that when an emergency stop button is pressed, all dangerous actions will stop without creating new hazards. The system must contain an accesable emergency stop button. When pressed, power to the pulse inverter will be cut off.

<sup>2</sup>
In order to avoid any sort of explosion or uncontrolled fire, pressure and temperature sensors will cut off power to the pulse generator if their values approach ignition conditions of Brown's gas.

<sup>3</sup>
Failure of the safety system can be minimized by creating redundancies in the system. Redundancies will be created by including 2 relay contacts for each componant in the safety system.

<sup>4</sup>
Halting gas production when there is no flame present ensures that there is no gas lingering in the system. This eleminates any hazard when the machine is not being used.
 
## Buildable Schematic
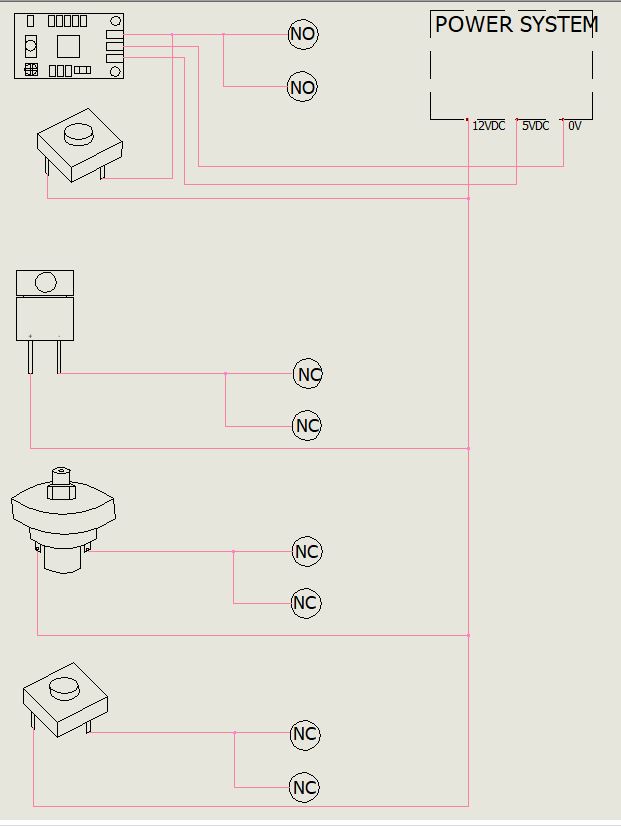
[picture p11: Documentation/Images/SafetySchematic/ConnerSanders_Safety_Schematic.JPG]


## Analysis
#### UV Sensor
The UV sensor is connected to 12VDC and ground from the power system. The output of this sensor is connected to a normally open relay. A button is also connected to this relay, so that when you are ready to start OH production, you can do so. The button separates the relay coil from 12VDC, so the coul is energized when the button is pressed. IF the sensor does not see a flame, and the button is not pressed, the circuit between the pulse inverter power and the pulse inverter is broken.

#### Temperature Sensor
The Temperature sensor separates 12VDC from the power system and a normally closed relay coil. When the sensor feels anything over 100 degrees Celcius, the circuit between the puls inverter power and the pulse inverter is broken.

#### Pressure Sensor
The pressure sensor separates 12VDC from the power system and a normally closed relay coil. When the pressure across the sensor rises to 15 psi, the circuit between the puls inverter power and the pulse inverter is broken.

#### Emergency Stop
The Emergency stop button separates 12VDC from the power system and a normally closed relay coil. When pressed, the circuit between the pulse inverter power and the pulse inverter is broken.

## BOM
| Device | Quantity | Price per Unit | Total Cost |
| --- | --- | --- | --- |
| UV flame detector | 1 | $8.13 | $8.13 |
| Pressure sensor | 1 | $88.02 | $88.02 |
| Temperature sensor | 1 | $7.28 | $7.28 |
| Emergency stop | 1 | $7.99 | $7.99 |
| Push button | 1 | $1.22 | $1.22 |
| Relay (NC) | 2 | $8.00 | $16.00 |
| Relay (NO) | 6 | $4.00 | $24.00 |
| ----------------------------------------------------- | -------- | -------------- | ---------- |
| Full System | -------- | -------------- | $152.64 |

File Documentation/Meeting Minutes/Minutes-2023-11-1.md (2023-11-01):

Week 11 - 40 minutes

Attendees: Brennan Angus, Matthew Beausoleil, Jacob Cooper, Wyatt Groves, Austin Jerrolds, and Conner Sanders

Discussed overall layout involving housing. Discussed the possibility of building a torch and also sensor concerns. Discussed status of all Sign-Offs. Discussed how everything should be connected without breadboards.

Group Decisions: none

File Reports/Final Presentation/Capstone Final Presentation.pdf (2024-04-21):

# Pulse-Inverted

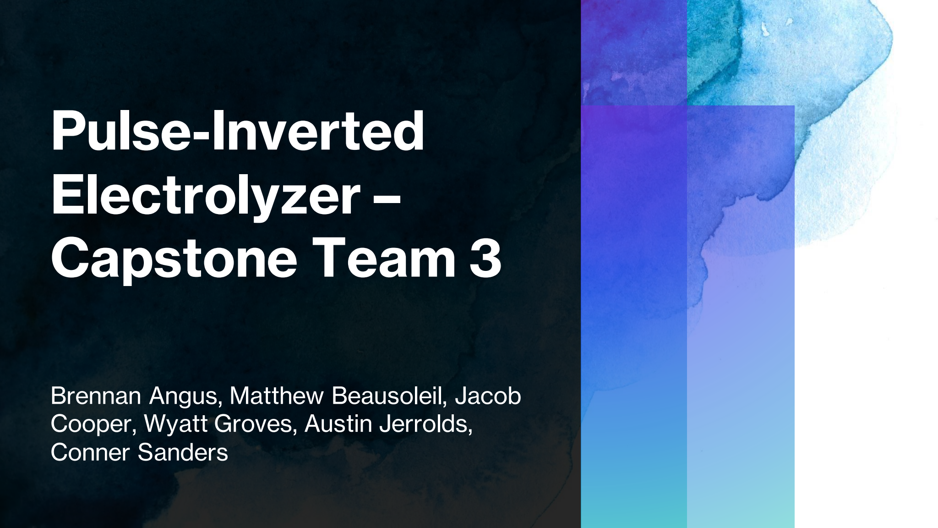
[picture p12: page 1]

# Electrolyzer – Capstone Team 3

Brennan Angus, Matthew Beausoleil, Jacob Cooper, Wyatt Groves, Austin Jerrolds, Conner Sanders

# The Problem is

- The goal of the project was to create a water electrolysis system with modifications intended to boost its energy efficiency.
- Modifications were also made to the base system to properly address public health risks associated with the project and comply with various safety standards.

# Standards

- 1910.103 OSHA – Storage, handling, and transportation
- NFPA 2 – Hydrogen Technolgies Code
- NFPA 54 – National Fuel Gas Code
- NFPA 70 – National Electrical Code
- ANSI Z21.1 - American National Standards Institute

# Design - Power

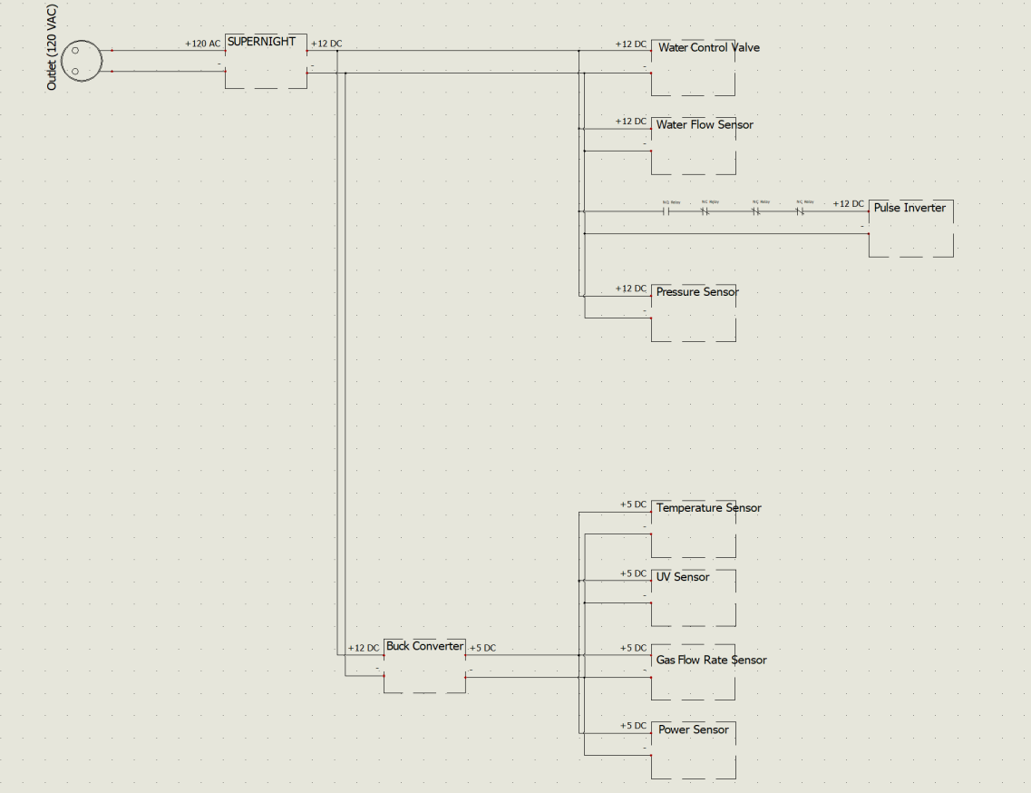
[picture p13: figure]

- What needs power?
- The biggest power draw is the electrolysis cell itself.
- When DC, it will draw
around 240 watts.
- To draw the 5 volts needed, a buck converter was used.

# Implementation -

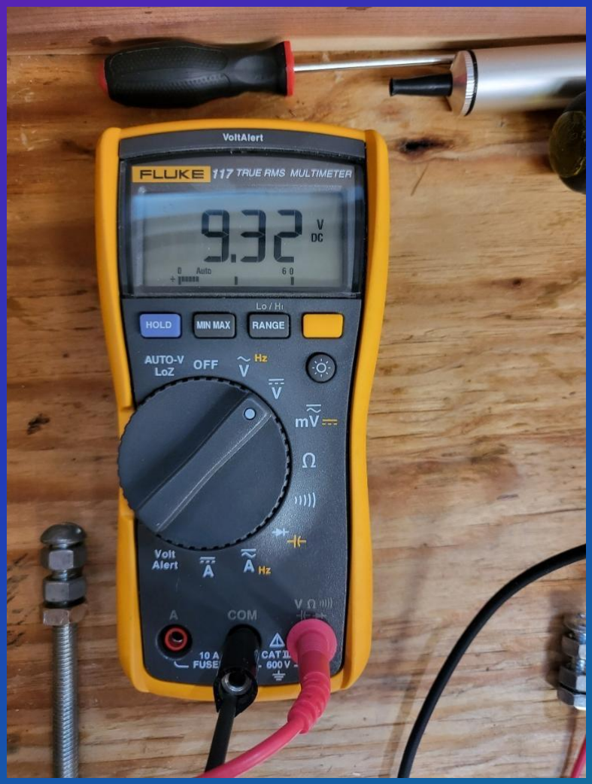
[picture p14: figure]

# Power

- Implementation is straightforward – just use a bus-bar.
- The biggest challenge was finding wire sizes for DC testing.
- The DC cell draws so much power it starts to lower the output of the supply.

# Design - Water

- Needed a way to sense the level of the Water level without being in the cell
- Had to ensure the was no backflow to make sure we would not contaminate the water supply
- Had make sure the water would stay at an appropriate level


# Implementation - Water

- Original Design did not work
- Needed to invert the signal from the sensor
- Could have used a micro-controller but went with an analog circuit

# Implementation - Water

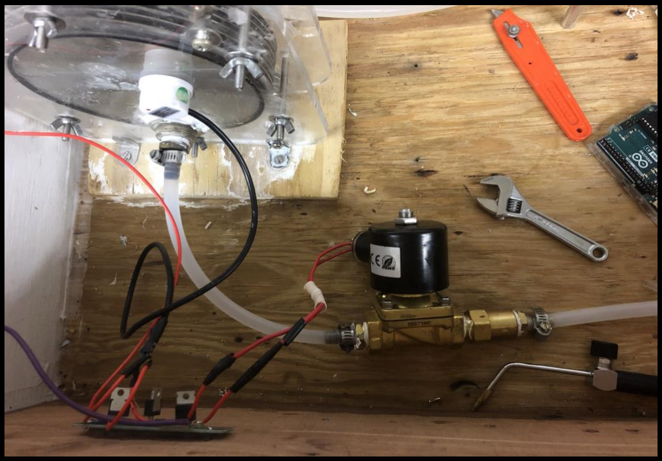
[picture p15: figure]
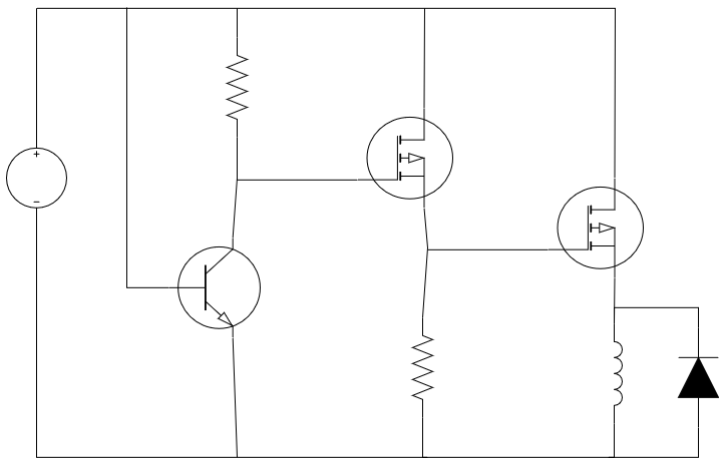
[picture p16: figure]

# Design - Electrolysis

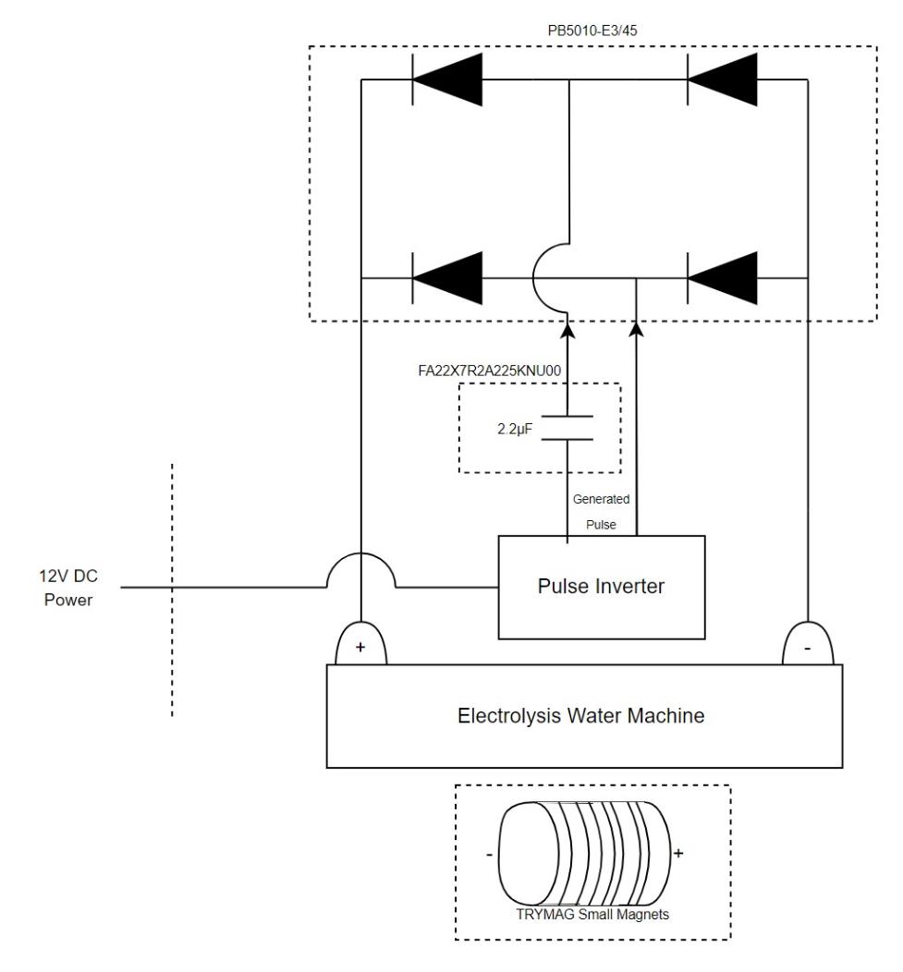
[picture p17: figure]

- Needs to include the electrolytic cell and the

tools for efficiency boosting

- Pulse inverter
- Rectifier
- Magnets
- Coupling capacitor

# Implementation - Electrolysis

- Everything was incorporated successfully.
- The expected AC pulses were produced from the pulse inverter.
- The AC voltage was then rectified properly.
- Magnets were attached to the outside of the cell.
- The auxiliary capacitors were replaced to adjust the duty cycle of the pulses.

# Design - Controller

- Arduino Uno for sensor readings, efficiency calculations, and serial output.
- Originally planned on using the SFM3003 for gas flow rate readings but the gas tube was too small to fit around the sensor.
- Switched to FS1012 which is an analog gas flow rate sensor.
- Adafruit INA260 for power readings.

# Implementation - Controller

- Accidentally desoldered resistors off the power sensor, new ones had to be ordered.
- The flowrate sensor originally was reading about 7.4 sccm while using 240 Watts but after trying to solder on wires and desolder the pins the sensor no longer behaved the same way.
- The power sensor was about 3-4 Watts off I think this was since the sensor was not grounded with the rest of the system.

# Implementation - Controller

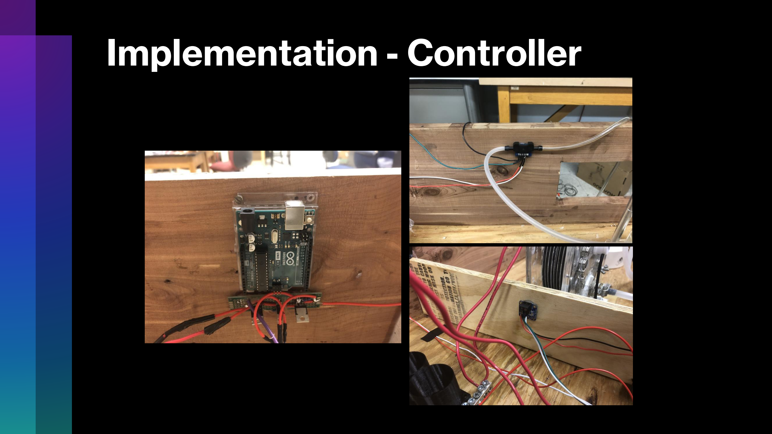
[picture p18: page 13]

# Design - Gas

- Handling gas once it is generated, there is no storage in the system.
- Gas Arrestor is used to prevent any combustion from going back into cell housing, this is used as a safety measure.
- Gas System prevents the backflow of flame from causing damage to the system

# Implementation - Gas

- The system was turned on, the torch was removed, and no flame was lit. After some time of gas producing the flame was then lit. This caused flame to be sent backwards towards the arrestor.
- The water in the arrestor expels the flame and preventing it from travelling towards the cell.

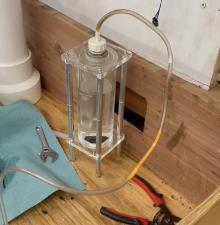
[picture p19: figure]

# Implementation - Gas

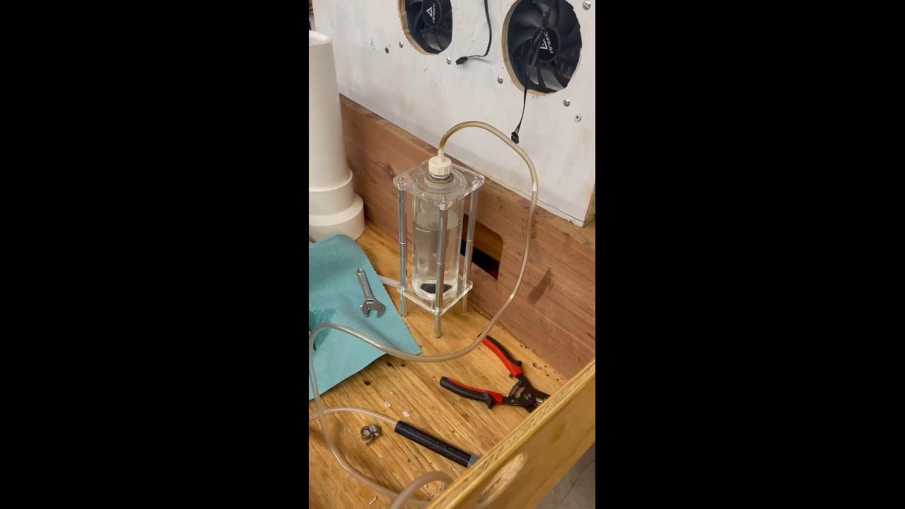
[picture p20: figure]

# Design - Safety

- Cut off power to the pulse inverter if the system becomes unsafe
- "Safe" is defined by conditions in which browns gas could ignite
- Temperature rises above 100 °C
- Pressure builds above 15 psi
- Design also includes user inputs to start/stop the system
- System is not producing a flame
- User presses the emergency stop button

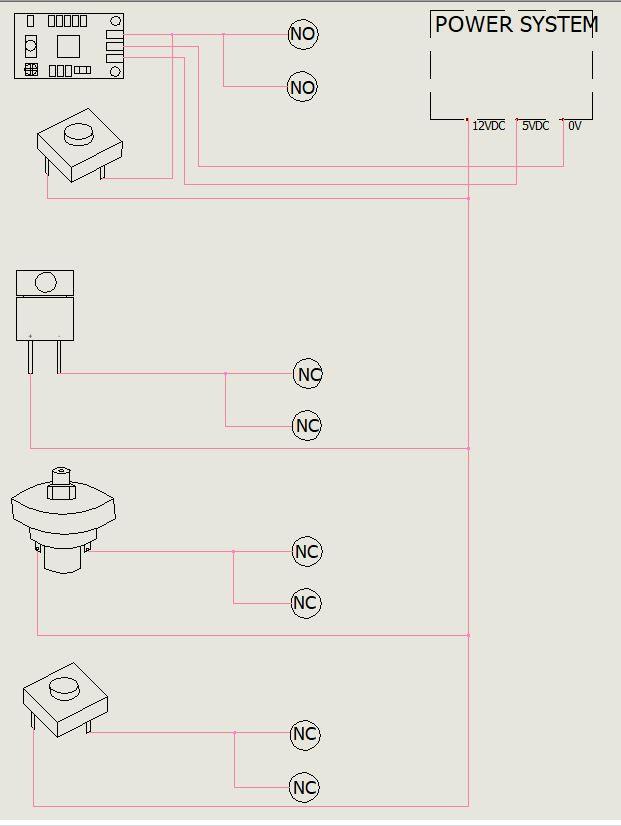
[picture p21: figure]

# Implementation - Safety

- Original flame sensor was supposed to detect light between 200-370 nm - this was not the case. A second temperature sensor was used instead.
- All other components behaved as expected and implementations went smoothly.

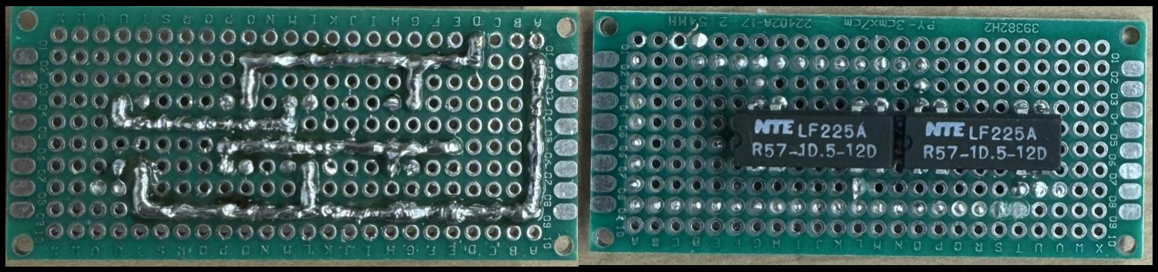
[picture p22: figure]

# Experimentation

- One of our measures of success was to improve the efficiency of electrolysis.
- The other measure of success we wanted to do was have a constant flame output.
- To be able to measure the input and output power of the system.
- The accuracy of the pulse generator outputs frequency voltage

# What's Next?

- We would like to increase the auxiliary capacitor.
- Implement a closed-loop feedback system for the pulse inverter's controller.
- We would like to change both the power input sensor and the gas output sensor.
- We would like a high sensor and low sensor for the water system.
- Use a flame sensor instead of a temperature sensor to detect flame output.

# Budget

Components | Price($)
Electrodes | 180
Pulse Generator | 90
Mini Compressor | 400
Hydrogen Sensor | 65
Housing System | 80
Gas System | 260
Micro-controller | 30
Total | 925
Components | Price($)
Controller | 155.72
Electrolysis | 120.9
Gas | 157.42
Power | 33.97
Safety | 152.64
Total | 620.65
Predicted | Real

# Demonstration

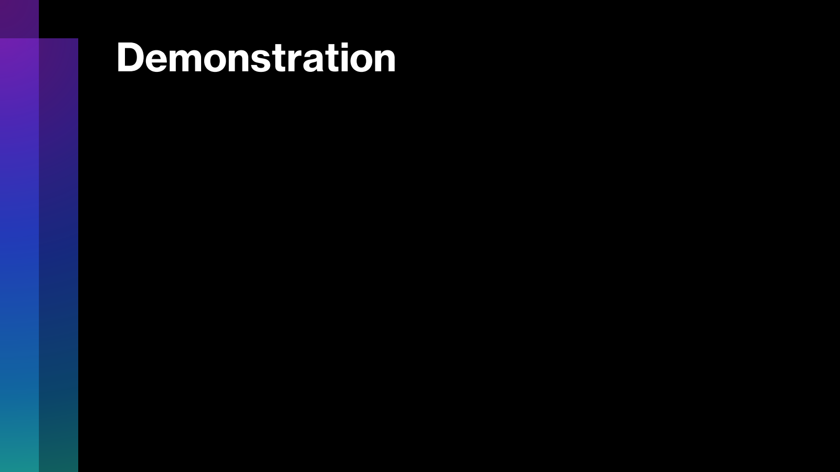
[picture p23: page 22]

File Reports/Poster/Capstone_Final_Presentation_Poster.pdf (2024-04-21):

# Pulse Inverted Electrolyzer

Brennan Angus, Matthew Beausoleil, Jacob Cooper, Wyatt Groves, Austin Jerrolds, Conner Sanders

## Executive Summary

The goal of the project was to create an electrolysis system and make it as efficient as possible, while also taking standards of safety into consideration. The system should create a constant flame while it is run. The standards to be met required a variety of additions to the basic electrolysis cell, including a water level sensor and an emergency stop button. While the electrolytic cell was pre-made, the overall system needed to be designed around it, with functional and spatial limitations being considered.

## What is Electrolysis?

Electrolysis is the process by which an electrical current is passed through a substance to trigger a chemical change. Water electrolysis occurs when a power source is connected to two electrodes which are immersed in water. When a voltage is created across the plates, water in the cell changes into hydrogen and oxygen gas. This results in the highly flammable mixture oxyhydrogen, commonly dubbed “Brown’s gas”.

## Architecture

## Efficiency Boosting

## Future Improvements

Lye | Pulse Inverter | Magnets
Lye (sodium hydroxide) is used to help boost the chemical splitting of water into hydrogen and oxygen gas. | The pulse inverter is used to generate high-magnitude electrical pulses in order to try to boost the system’s efficiency. The pulses are rectified so that the polarity of the system is unchanging. | The magnets are placed onto the electrolysis cell in order to bias the ions’ location in the solution for faster oxyhydrogen generation.

Pictured (left to right): Austin Jerrolds, Brennan Angus, Jacob Cooper, Wyatt Groves, Conner Sanders, Matthew Beausoleil

## Predicted vs Real BOM

Predicted | Real

## Experimental Results

- Pulse inverter: The pulse inverter running at a higher frequency than what it is currently capable of could result in the cell being sufficiently powered.
- Gas output sensor: The sensor used by the system was ruined by the oxyhydrogen being output. Using a different sensor would allow the output to be measured properly.
- Magnets: The magnets used on the cell didn’t end up having notable effects. Using stronger magnets could help make the electrolysis process more efficient.
- Electrolysis cell: While the cell that was used functioned overall, it had leaking issues that needed to be addressed and it proved to be inconvenient to take apart and work with.

In experimentation, many constraints were tested and met. Functionality constraints included but were not limited to constant voltage supplies of 5V and 12V, the pulse generator’s output being rectified, and the prevention of water backflow out of the system. Safety constraints included but were not limited to the cell not being reactive with sodium hydroxide, the system having no dangerous exposed wires, and the inclusion of a functional emergency stop button. Constraints of accurate measurement, gas not being produced when there is no flame, and the inclusion of magnets were the only ones not met.

Controller System Schematic

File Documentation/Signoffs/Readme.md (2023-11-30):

# Signoffs
All completed Signoffs
1. [Electrolysis System](https://github.com/ConnerSanders/Pulse-Inverted-Electrolyzer/blob/main/Documentation/Signoffs/Electrolysis_System.md)
2. [Controller System](https://github.com/ConnerSanders/Pulse-Inverted-Electrolyzer/blob/main/Documentation/Signoffs/Controller_System.md)
3. [Safety System](https://github.com/ConnerSanders/Pulse-Inverted-Electrolyzer/blob/main/Documentation/Signoffs/Safety_System.md)
4. [Water System](https://github.com/ConnerSanders/Pulse-Inverted-Electrolyzer/blob/main/Documentation/Signoffs/Water_System.md)
5. [Power System](https://github.com/ConnerSanders/Pulse-Inverted-Electrolyzer/blob/main/Documentation/Signoffs/Power_System.md)
6. [Gas System](https://github.com/ConnerSanders/Pulse-Inverted-Electrolyzer/blob/main/Documentation/Signoffs/Gas_System.md)

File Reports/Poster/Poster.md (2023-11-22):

## Poster size expectations

The poster should be 42 by 24. 

## Power point instructions

The college of engineering has poster templates available via the library website. However, the posters are not sized appropriately for the departments expectations. Be sure to resize the poster in power point in the following manner.

1. Choose “DESIGN”
2. Choose “Slide Size”
3. Choose “Custom Slide Size”
4. Choose “Widescreen”
5. Width: 42”
6. Height: 24”
7. Slide Orientation: “Landscape”
8. Design your poster
9. Save your slide as a PDF (within PowerPoint)

Be sure to also include a minimum of 2cm of border around the outside of the poster.

## Overleaf/Latex instructions

You may instead choose to use overleaf to make the poster. A template is included [here](https://github.com/TnTech-ECE/CapstoneStarterRepo/tree/main/Reports/Poster%20Template). Upload this template to overleaf and customize as necessary. The template is already the appropriate size.

## Other poster resources

[University Logos](https://www.tntech.edu/ocm/marketingtoolkit/logos.php)

[Poster Making Guide (INCORRECT SIZE for ECE - still a good resource)](https://www.tntech.edu/library/poster.php)

## What to include in the poster

The poster should capture your entire project. At a minimum that would include:

1. The problem 
2. Necessary constraints (things that an observer needs to know - not every detail)
3. The solution (show off your design and artifacts)
4. The most relevant or interesting analysis results from the signoffs
5. The most relevant experimental results regarding your solutions success (in an appropriate format ie. graph, table, or figure) - do not include every detail
6. Pictures of the system are good to include
7. Cad models are good to include
8. Budgets are good to include
9. Team pictures are good to include

Each team has the opportunity to put their own identity into the poster and it will hang in the hall for a year. So, be sure to represent yourselves well. Remember to look at past posters for ideas about what to include and how to style the poster.

## What not to do

1. Don't leave too much open white space. Use the poster's space to tell the story of your project.
2. Don't make the text too small to read. The poster should be legible from 5 feet away.
3. Don't make images unnecessarily large. But do make them appropriately large so that they all text is legible.
4. Don't submit the poster without revising it. Mistakes are going to happen.

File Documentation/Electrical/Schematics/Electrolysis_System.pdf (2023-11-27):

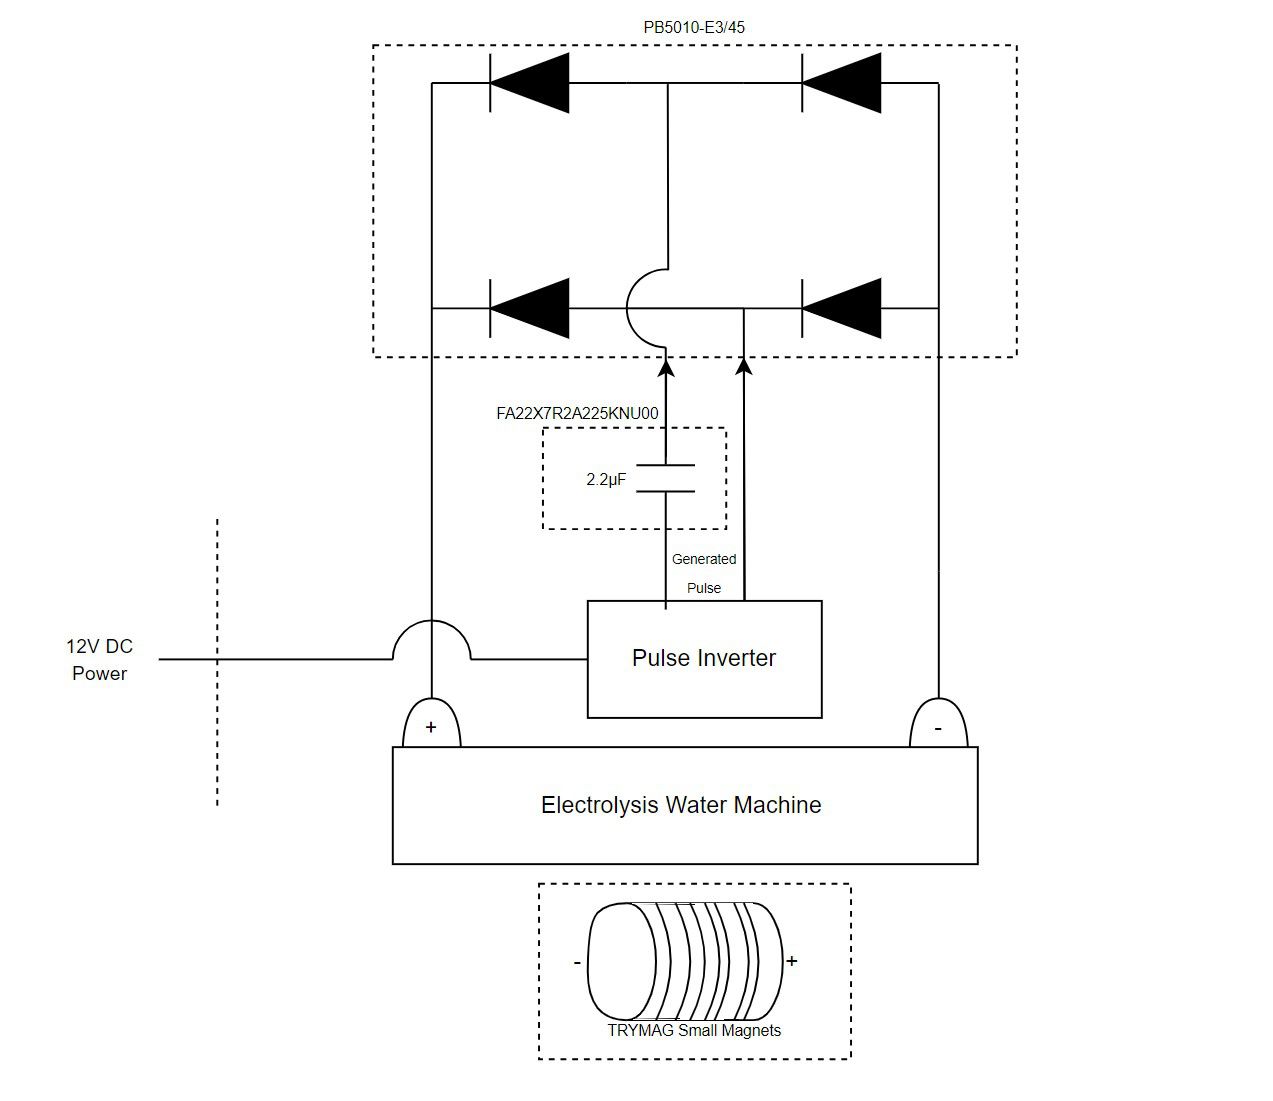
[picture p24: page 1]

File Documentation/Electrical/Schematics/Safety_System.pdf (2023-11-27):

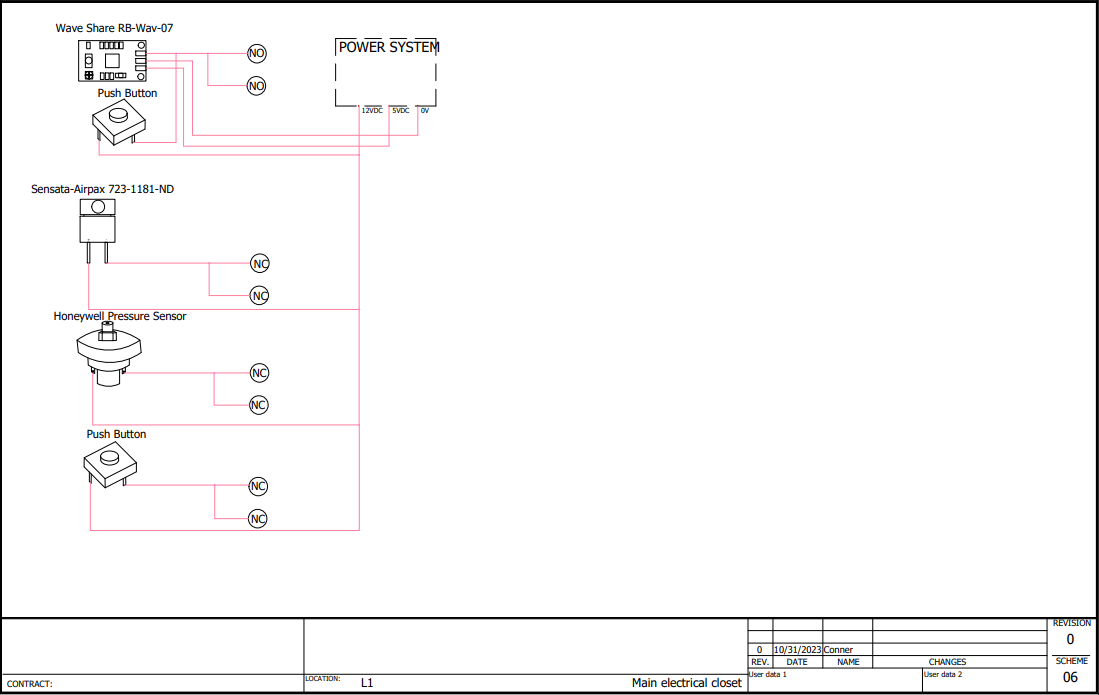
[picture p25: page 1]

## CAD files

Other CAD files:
Documentation/Electrical/Schematics/Sources/Power_Subsystem.dwg
Documentation/Electrical/Schematics/Sources/water_system.dwg
Documentation/Electrical/Schematics/Sources/Safety_System.dwg
Documentation/Electrical/Schematics/Sources/Controller_System.dwg

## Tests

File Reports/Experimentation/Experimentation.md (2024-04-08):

# Experimental Analysis Report

## Introduction
The purpose of the Experimental Analysis is to test if project constraints are being met and to document the experiments used to measure success.  
### Requirements Table
| **Constraint** | **Constraint Description** | **Subsystem** |
|---|---|---|
| 1 | Shall accurately measure the electrical efficiency of the electrolyzer | Controller  |
| 2 | Display output shall be easy to read and simplistic. | Controller  |
| 3 | The material of the electrolytic cell housing shall not be reactive with sodium hydroxide. | Electrolysis  |
| 4 | The system shall include a pulse generator and permanent magnets to boost efficiency. | Electrolysis  |
| 5 | The pulse generator’s output should be rectified. | Electrolysis  |
| 6 | The water in the cell shall automatically refill when below 2/3rds of the cell's capacity. | Water  |
| 7 | The water system fittings will use non-corrosive materials for fittings. | Water  |
| 8 | The water system shall prevent backwards flow of water. | Water  |
| 9 | The system shall convert wall AC Voltage to DC voltage. | Power  |
| 10 | The system shall be able to supply 5 VDC. | Power  |
| 11 | The system shall be able to supply 12 VDC. | Power  |
| 12 | The system shall have no dangerous exposed wires and shall be grounded as needed. | Power  |
| 13 | Shall contain an emergency-stop button | Safety |
| 14 | Shall shutoff if pressure and temperature approach ignition conditions of Brown's gas | Safety |
| 15 | System monitors must be designed with redundancies | Safety |
| 16 | System shall not produce gas unless there is a flame present. | Safety |
| 17 | Gas system shall prevent the backflow of flame from causing damage to the system. | Gas |

## Results

### Constraint 1 - Shall accurately measure the electrical efficiency of the electrolyzer 

#### Experimental Design

First, the power used will be measured using an oscilloscope then that value will be compared to the power sensor to confirm its accuracy. Lastly, the gas flow rate will be converted to watts to compute efficiency.

#### Results

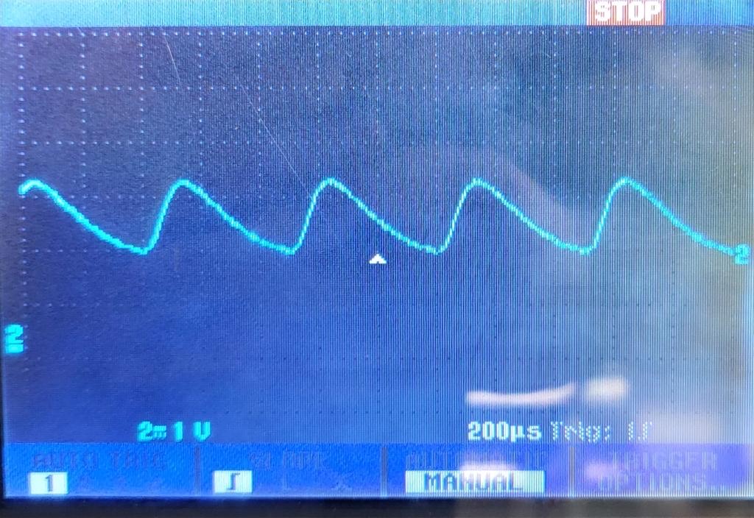
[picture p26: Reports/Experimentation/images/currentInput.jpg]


##### Current Input

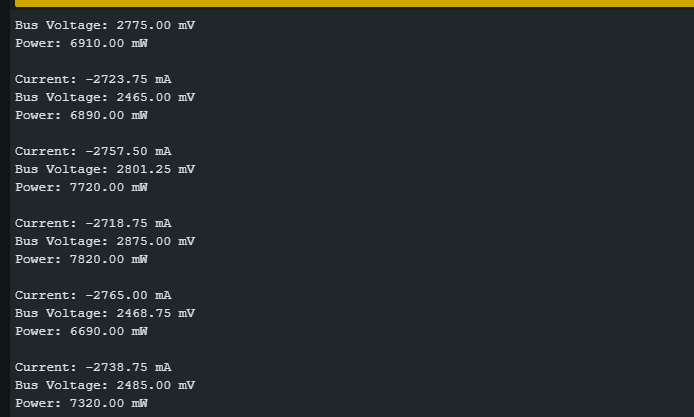
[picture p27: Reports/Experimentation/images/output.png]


##### Power sensor output

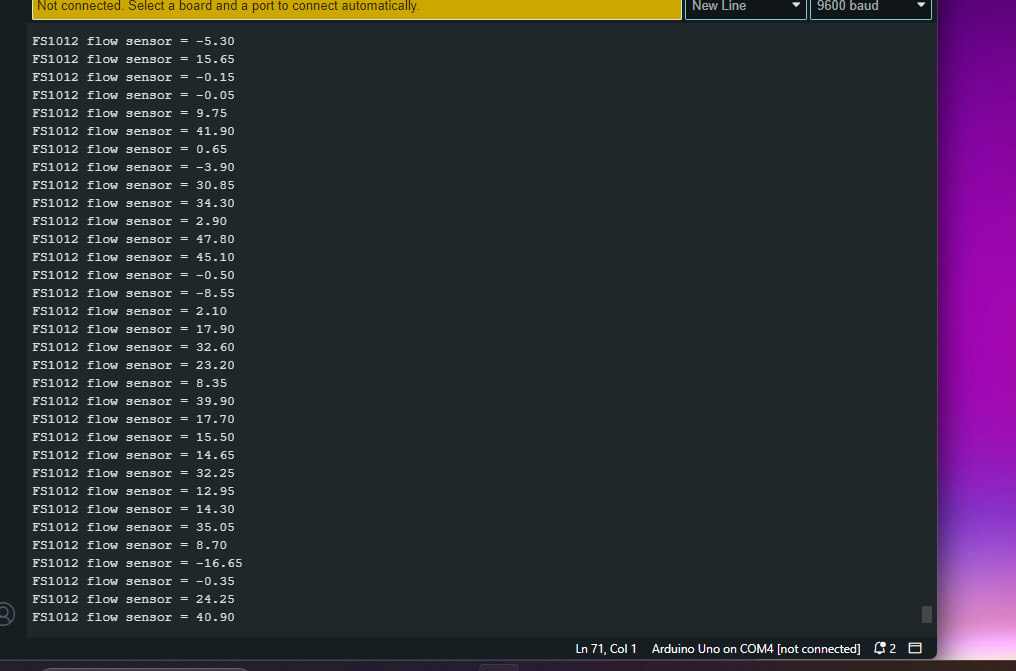
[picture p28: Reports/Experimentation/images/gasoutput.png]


##### Flow rate sensor output in sccm

The input voltage is 12 volts. Due to the surging current, we will use the rms of the current to calculate the power into the cell. The cell had an input rms power of about 12.73 Watts. The power sensor is reading around 6-7 Watts so there is an error with the power sensor. Converting the gas output to Watts we achieve an efficiency rating of 2,600 so there is an error with how the flow rate sensor is reading.

#### Conclusion

This constraint was not met.

### Constraint 2 -  Display output shall be easy to read and simplistic.

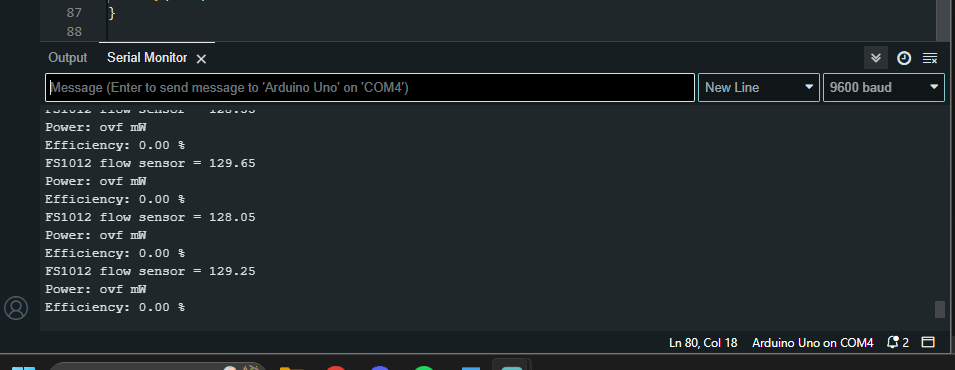
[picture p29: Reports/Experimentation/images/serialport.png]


##### The sensor data can be easily observed with appropriate units, new lines for each output were added for clarity.

#### Conclusion

Constraint was met.

### Constraint 3 - The material of the electrolytic cell housing shall not be reactive with sodium hydroxide.

This constraint was not traditionally tested but was met. 

### Constraint 4 - The system shall include a pulse generator and permanent magnets to boost efficiency. 

#### Experimental Design

The efficiency should be measured with no pulse inverter and no magnets to determine a base efficiency. Once efficiency is determined efficiency can be retested and compared to determine if there is an increase.

#### Results

A pulse generator was fitted but not the originally planned version. This pulse inverter is still a work in progress for the team. Magnets were not fitted because efficiency was not accurately determined yet.

#### Conclusion

This constraint was not met.

### Constraint 5 - The pulse generator’s output should be rectified.



##### Current Input to Pulse Inverter

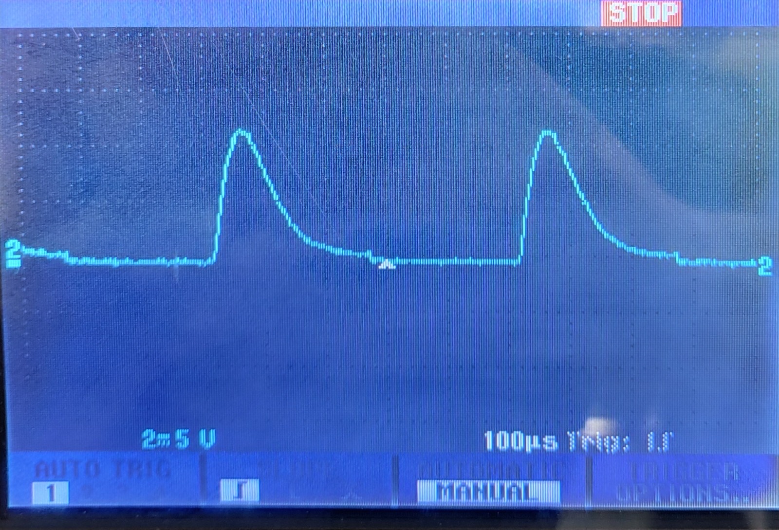
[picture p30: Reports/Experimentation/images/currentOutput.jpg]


##### Current Output to Pulse Inverter

The current output waveform has been rectified. The negative part of the waveform has been removed.

#### Conclusion

This constraint was met.

### Constraint 6 - The water in the cell shall automatically refill when below 2/3rds of the cell's capacity. 

#### Experimental Design

Since the cell does not use as much water as expected to conduct this experiment the water will be removed from the cell. The sensor will then be placed above and below the current water level to see how the water flow valve behaves. 

#### Results

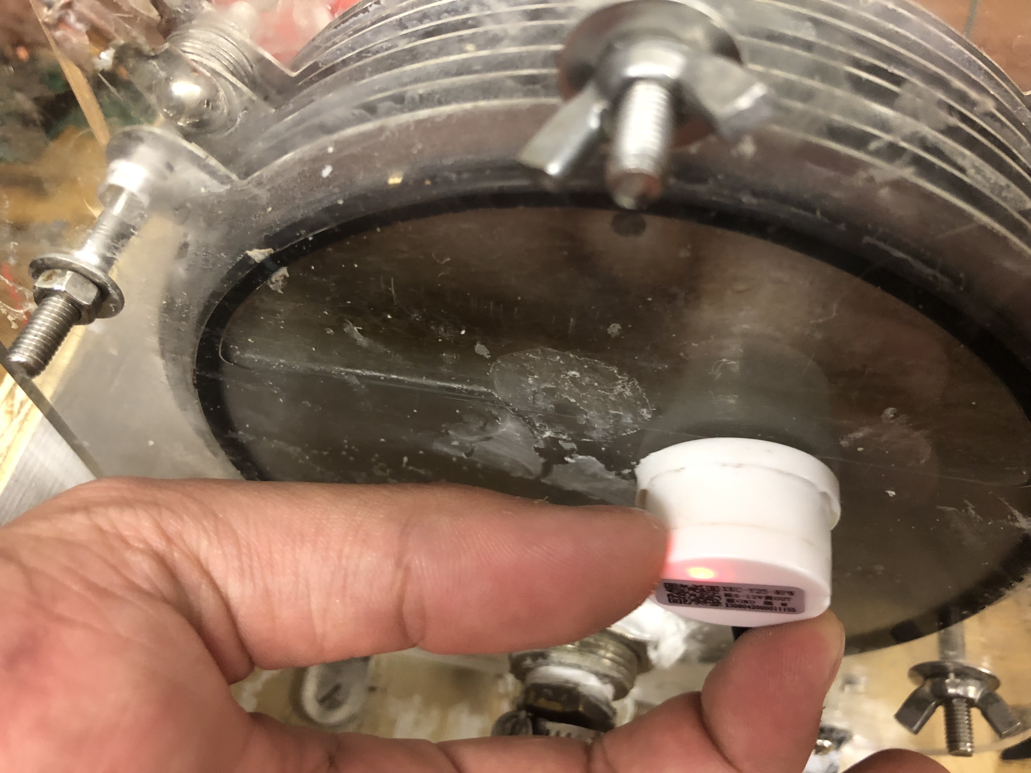
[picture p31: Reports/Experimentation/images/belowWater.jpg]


##### Sensor placed below the water line.

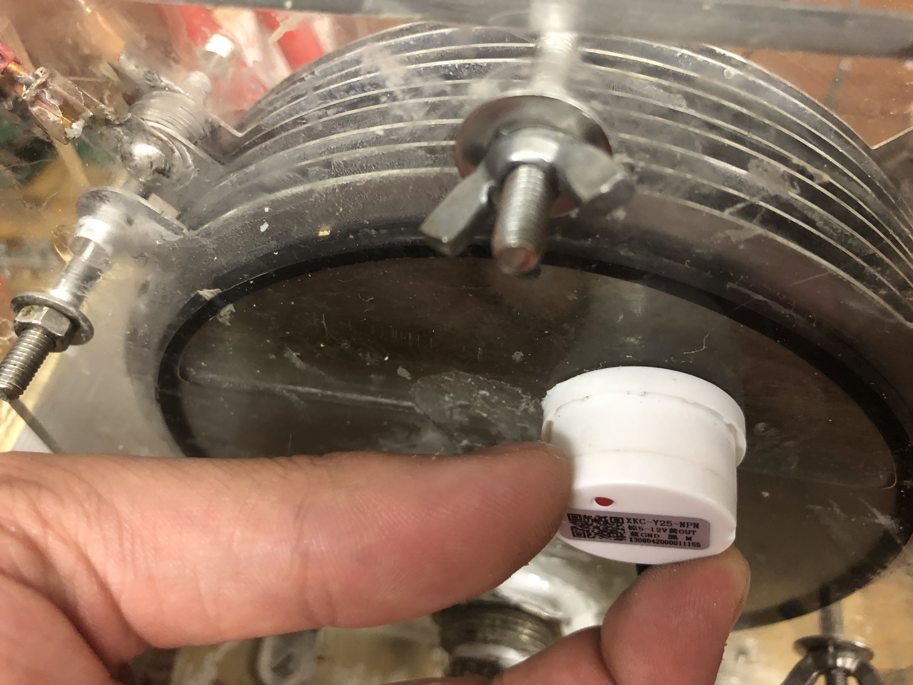
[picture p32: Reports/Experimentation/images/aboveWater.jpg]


##### Sensor placed above the water line.

While the sensor was not able to detect water the valve allowed water into the cell. While the sensor was able to detect water the valve was shut. The sensor is placed at the 2/3rds mark as per the constraint and has the intended behaviour of the water system.

#### Conclusion

This constraint was met.

### Constraint 7 - The water system fittings will use non-corrosive materials for fittings.  

This constraint was not traditionally tested but was met. 

### Constraint 8 -  The water system shall prevent backwards flow of water. 

#### Experimental Design

A backflow valve will be fitted to the system. The system will be filled with water and then removed from the water source. The backflow valve should keep the water inside the cell.

#### Results

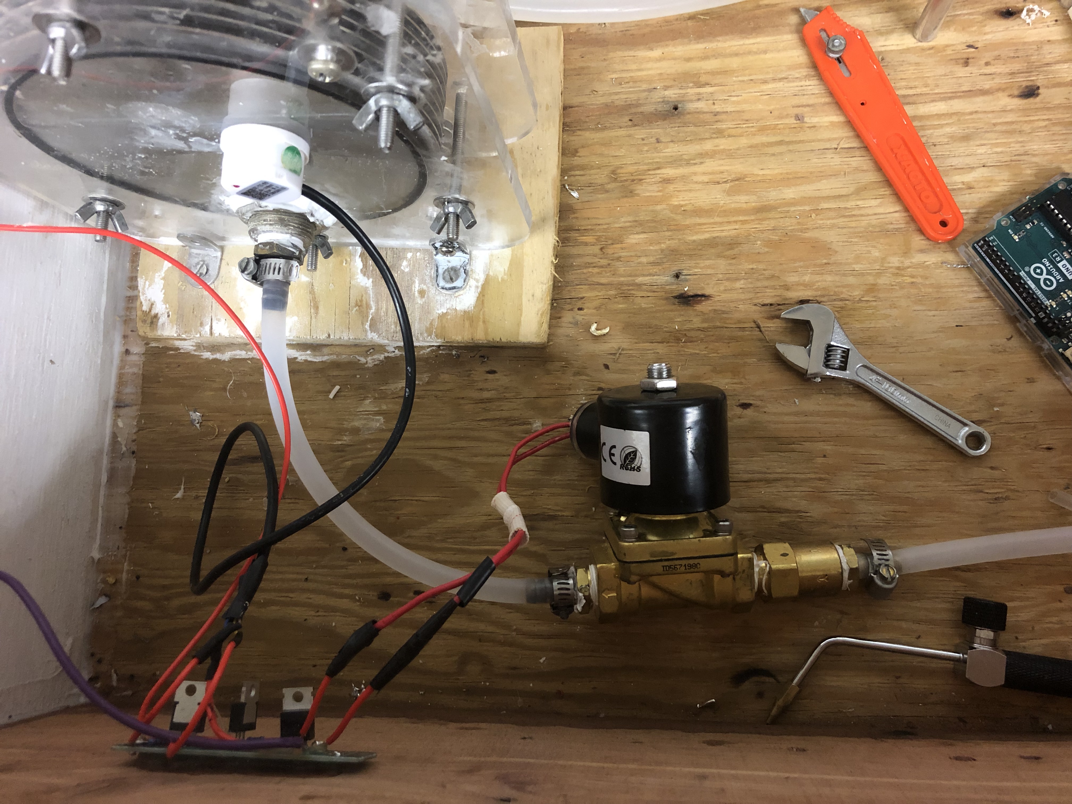
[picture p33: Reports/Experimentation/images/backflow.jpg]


The backflow valve to the right of the water valve keeps the water contained inside the cell.

#### Conclusion

This constraint was met.

### Constraint 9 - The system shall convert wall AC Voltage to DC Voltage. 

This constraint was not traditionally tested but was met.

### Constraint 10 - The system shall be able to supply 5 VDC.

#### Experimental Design 

The goal of this experiment is to verify that any components in the system that need 5 Volts are receiving the required power for them to function.

This was tested by placing the positive end of a Digital Multimeter along the positive 5V rail in the system and the negative end of the Multimeter along the ground rail of the system. Through this process, we measured the voltage.

#### Results

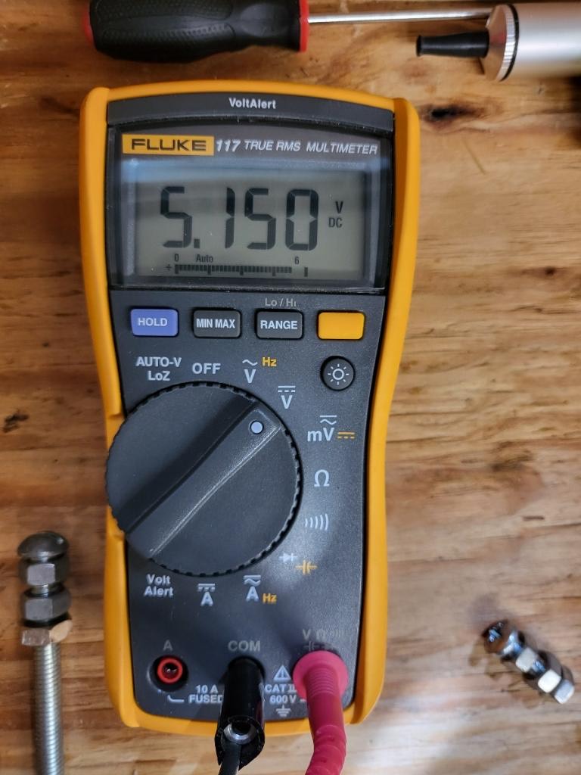
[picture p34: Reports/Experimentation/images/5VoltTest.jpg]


The power supply is providing the correct voltage to the 5 Volt rail.

#### Conclusion

The constraint has been met.

### Constraint 11 - The system shall be able to supply 12 VDC.   

#### Experimental Design 

The goal of this experiment is to verify that any components in the system that need 12 Volts are receiving the required power for them to function.

This was tested by placing the positive end of a Digital Multimeter along the positive 12V rail in the system and the negative end of the Multimeter along the ground rail of the system. Through this process we measured the voltage.

#### Results 

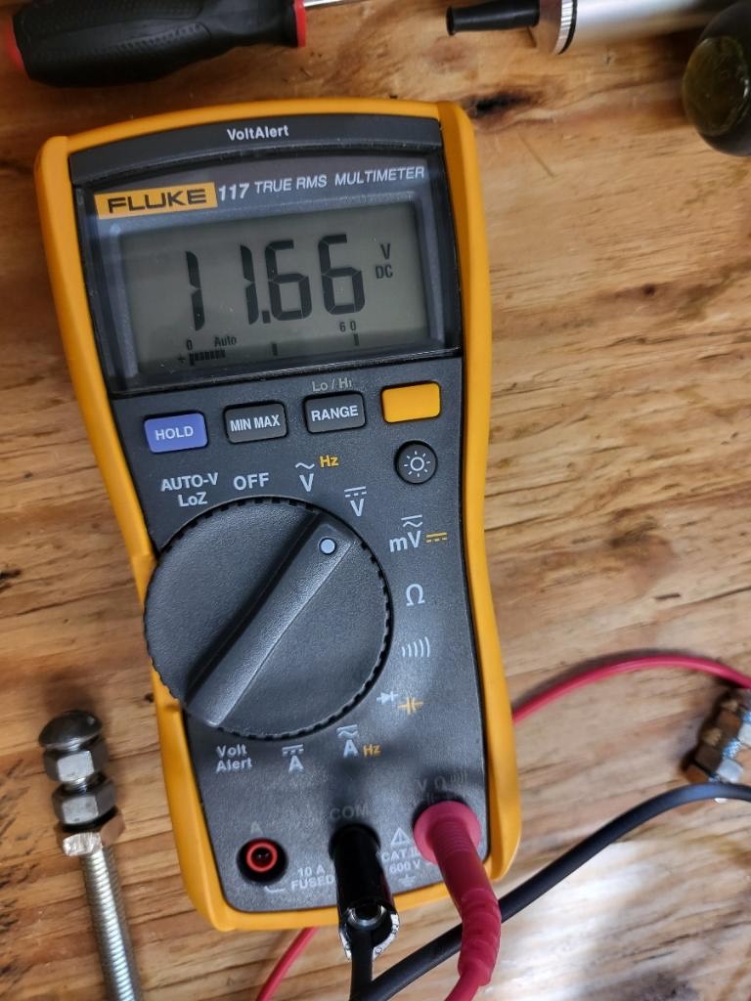
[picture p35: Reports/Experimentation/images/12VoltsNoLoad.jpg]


##### Voltage output when the power supply is on but the system is not active.



##### Voltage output under load.

The power supply is providing the correct voltage to the 12 Volt rail, but when the cell is running, the resistance of the load is so small that the voltage drops slightly to 9 volts and the current increases to account for this voltage drop. The other circuits in the system remain at full functionality, however, so this does not affect performance in any way.

#### Conclusion

The constraint has been met.

### Constraint 12 - The system shall have no dangerous exposed wires and shall be grounded as needed.

This constraint was not traditionally tested but was met. 

### Constraint 13 - Shall contain an emergency stop button

#### Experimental Design
When the emergency stop button is pressed, the power to the pulse inverter must be cut off. Output voltage of the estop button is measured using a multimeter.

#### Results




Voltage drops to 0V when emergency stop is pressed.

#### Conclusion
Constraint was tested and passed.

### Constraint 14 - Shall shut off if pressure and temperature approach ignition conditions of Brown's gas
#### Experimental Design
The temperature sensor was wired into the safety circuit. A heat gun was used to heat the temperature sensor. Since the system does not need to cut off at exactly 100 degrees celcius, I assume the temperature spec of the sensor is accurate enough (no temperature measurement taken). A multimeter was used to read the voltage at the output of the circuit.

The pressure sensor was wired into the safety circuit. A bike pump was used to pressurize the sensor. Since the system does not need to cut off at ecactly 15 psi, I assume the pressure spec of the sensor is accurate enough (no pressure measurement taken). A multimeter is used to read the voltage output of the circuit.

#### Results



The voltage output of the circuit drops to 0V after some time of heating the temperature sensor.




The voltage output of the circuit drops to 0V after pressurizing the sensor.

#### Conclusion
Temperature constraint was tested and passed. Pressure constraint was tested and passed.

### Constraint 15 - System monitors must be designed with redundancies

#### Experimental Design
Relay outputs were separated and tested independently while still connected to the same circuit.

#### Results



The safety circuit has 2 relays that have their own independent outputs.

#### Conclusion
Constraint was tested and passed

### Constraint 16 - System shall not produce gas unless a flame is present

#### Experimental Design
Flame was held up to the flame sensor and the output voltage was observed.

#### Results
The output of the flame sensor did not change from 0 volts. A new flame sensor has been ordered, the original flame sensor does not perform as expected.

#### Conclusion
Constraint was tested but did not pass.

### Constraint 17 - Gas system shall prevent the backflow of flame from causing damage to the system.

#### Experimental Design 
The system was turned on, the torch was removed, and no flame was lit. After some time of gas producing the flame was then lit. This caused flame to be sent backwards towards the arrestor. 

#### Results 





The water in the arrestor expelled the flame and prevented it from travelling towards the cell. 

#### Conclusion 

This constraint was met.

## Conclusion

| **Constraint** | **Constraint Description** | **Constraint Met?** |
|---|---|---|
| 1 | Shall accurately measure the electrical efficiency of the electrolyzer | Controller  |
| 2 | Display output shall be easy to read and simplistic. | Yes |
| 3 | The material of the electrolytic cell housing shall not be reactive with sodium hydroxide. | Yes |
| 4 | The system shall include a pulse generator and permanent magnets to boost efficiency. | No  |
| 5 | The pulse generator’s output should be rectified. | Yes |
| 6 | The water in the cell shall automatically refill when below 2/3rds of the cell's capacity. | Yes |
| 7 | The water system fittings will use non-corrosive materials for fittings | Yes |
| 8 | The water system shall prevent backwards flow of water. | Yes |
| 9 | The system shall convert wall AC Voltage to DC voltage. | Yes |
| 10 | The system shall be able to supply 5 VDC. | Yes |
| 11 | The system shall be able to supply 12 VDC. | Yes |
| 12 | The system shall have no dangerous exposed wires and shall be grounded as needed. | Yes |
| 13 | Shall contain an emergency-stop button | Yes |
| 14 | Shall shutoff if pressure and temperature approach ignition conditions of Brown's gas | Yes |
| 15 | System monitors must be designed with redundancies | Yes |
| 16 | System shall not produce gas unless there is a flame present. | No  |
| 17 | Gas system shall prevent the backflow of flame from causing damage to the system. | Yes |

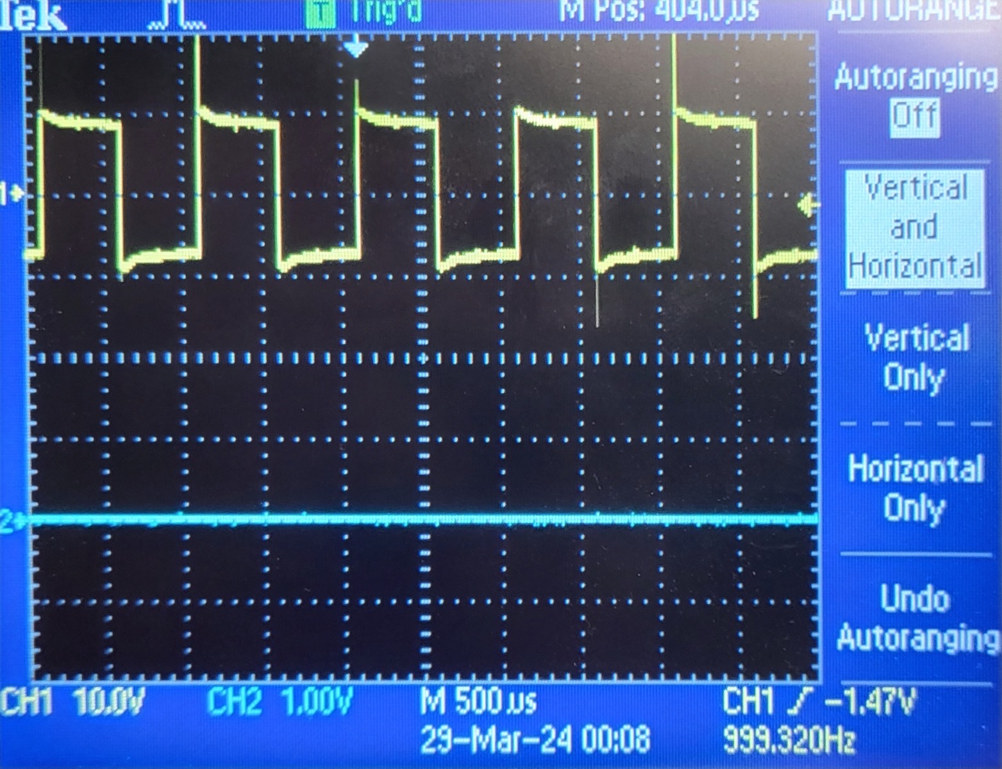
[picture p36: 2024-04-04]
Reports/Experimentation/images/voltageInput.jpg

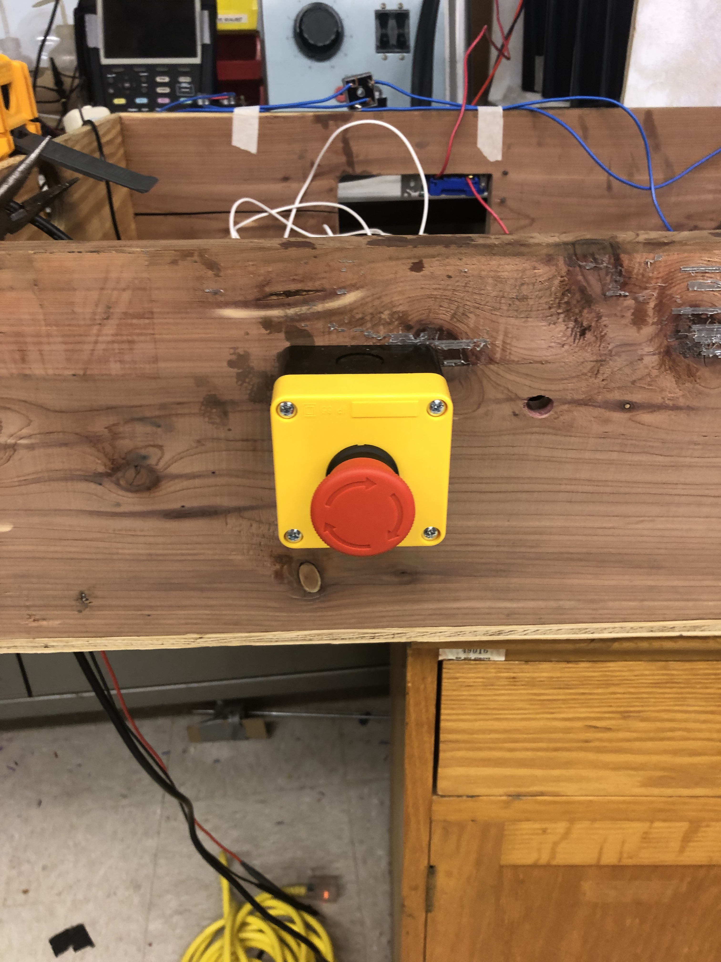
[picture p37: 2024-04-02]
Reports/Experimentation/images/estop.jpg

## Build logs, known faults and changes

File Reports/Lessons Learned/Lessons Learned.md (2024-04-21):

# Lessons Learned

## Brennan Angus
- Overall, the project went well. Organizationally, the team did what we were supposed to do and tended to do it in a timely manner. Communication tended to be lacking.
- One unanticipated problem was the need for adjusting capacitance values and working around impractical physical characteristics of components.
- If I were to do it again, I would take more initiative and push for more communication within the group. Better communication about individuals' and the whole group's progress could have served us well.
- Good practices included consultation of Professor Roberts for help when the team or I individually was unsure of how to approach an issue.
- I would emphasize the importance of getting everything done as efficiently (early and effectively) as possible. I would also emphasize the importance of initiative and honest communication.
- I learned how to approach design problems and take advantage of online research. I also improved my practical skills related to lab work.

## Matthew Beausoleil
- The conceptual side of the project was easier as it is just theory, and it's easier for everyone to collaborate. When it came to design, it got pretty crowded when more than three people had their hands in the box.
- For me, I was not anticipating the signal from the water sensor being inverted and the lack of documentation on the internal circuit, so there had to be some testing to see how the sensor work then re-design a circuit to work with the sensor.
- I have a terrible problem with not delegating work enough, and where I was better than past projects. I need to better as it left me pretty burnt out towards the end.
- I stand by our best practice of KISS "Keep it stupid simple". There is no need to make things overly complicated if it doesn't need to be.
- Try to front-load capstone so that when the final semester comes it's not a wall of assignments. 
- I feel like I can say I required my knowledge of Electronic design as I had to stare at several analog circuits and understand what was happening when they broke.

## Jacob Cooper
- I had a great time working on the project and I strongly feel we worked on this efficiently and as a team
- As we got into later parts of the project things did not run or work as intended and some sections didn't have enough time for us to solve them.
- Working in this sort of team was very beneficial for myself and learning how to cooperate smoothly with others. I believe everyone had a common goal and everyone got along well.
- I enjoyed how Jesse revered to us as engineers and it really felt like I was given a project just like how it will be in my future endeavours.
- For those future students, try to soak in the experience and don't treat it like a normal college project, consider it like a job.
- The biggest skills I acquired was simply working with a team and how to manage meetings outside class time. Also learning how to properly time management with this big project.
  
## Wyatt Groves

- As a whole, I feel that the project went well on the more conceptual side of things. We managed to quickly and efficiently make designs and plans for what we were going to do moving forward. During some of the later parts of the project, we didn't run quite as smoothly, as some sections could not get addressed in time for us to fix them.
- The sensors for the power and the flow rate are extremely finicky and we could never quite figure out how they worked, or if they were even working at all. This made trying to acquire numerical data for efficiency very hard, which was frustrating.
- I would like to restructure the way that we worked and how we checked the progress of the other systems.
- It was good practice to always try to understand as much about the project as a whole as I could so that I could help if another member was falling behind or needed assistance. 
- Doing everything you can to make sure you get assignments done well before the deadlines was important. No matter how far ahead we got, I still feel like I need more time to do some work.
- Learning to work in a group like this is much different than a typical project group for a class. It felt more like how I imagine the real workforce is.

## Austin Jerrolds

- Overall, I think we managed our technical assignments very well we were on top of deadlines never in crunch time. Once we got to the second half of the semester we were not organized very well and were not as on top of the project.
- We had some problems with sensors and components not functioning as intended and took a lot of troubleshooting.
- If I were to do it over again I would begin building as soon as I had parts. I would also spend a lot more time making sure that we designed as a team as opposed to having what seemed like 6 differently designed subsystems.
- I think it is best practice to be involved in the entire design process. The more you know about everyone's system and progress the smoother the project will go.
- My words of wisdom that I would pass on to future students is to communicate with your teammates as much as possible and to start working on any assignment or the building as soon as you can. Worst case scenario you finish the task early.
- I learned a lot about the entire project life cycle, especially in the technical phase. I think my writing has improved a lot and I've my eyes have been opened to things in the design process that I wouldn't have normally thought about.

## Conner Sanders

- I thought the project went well. Technically my system was simple, and I had minimal issues with designing and building. Organizationally, I think our team did a good job with the division of labor and time management. 
- Towards the end, components started failing or not acting as expected. This delayed the final build of the project and added some stress. 
- Putting more effort into building and testing earlier in the semester would relieve a lot of stress during crunch time.
- A "best practice" that I identified was consulting the team as a whole when I encountered any issue. It always helps to get different opinions and ideas when finding solutions.
- I would tell future students to do as mutch capstone work as possible, as soon as possible. Deadlines are not hard to meet, so long as you are actively working to meet them.
- Working with a larger team was both a challenge and a blessing in this scenario. It is sometimes hard to manage the division of labor and manage time with a team of this size. I think I got better at understanding what needs to be done, and how I can help meet deadlines, in a group setting.

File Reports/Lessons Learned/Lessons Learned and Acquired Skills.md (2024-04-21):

# Lessons Learned

This document should have a section for each team member. Each engineer should respond to these:

- Reflect on the project, both technical and organizational. What went well? What didn’t go well? 
- What unanticipated problems occurred? 
- What would you do differently if you were to do it over again? 
- What “best practices” have you identified? 
- What words of wisdom would you pass on to future students?
- What new knowledge or skills did you acquire throughout capstone.

Create a subsection addressing each of the above questions in your section of the document.

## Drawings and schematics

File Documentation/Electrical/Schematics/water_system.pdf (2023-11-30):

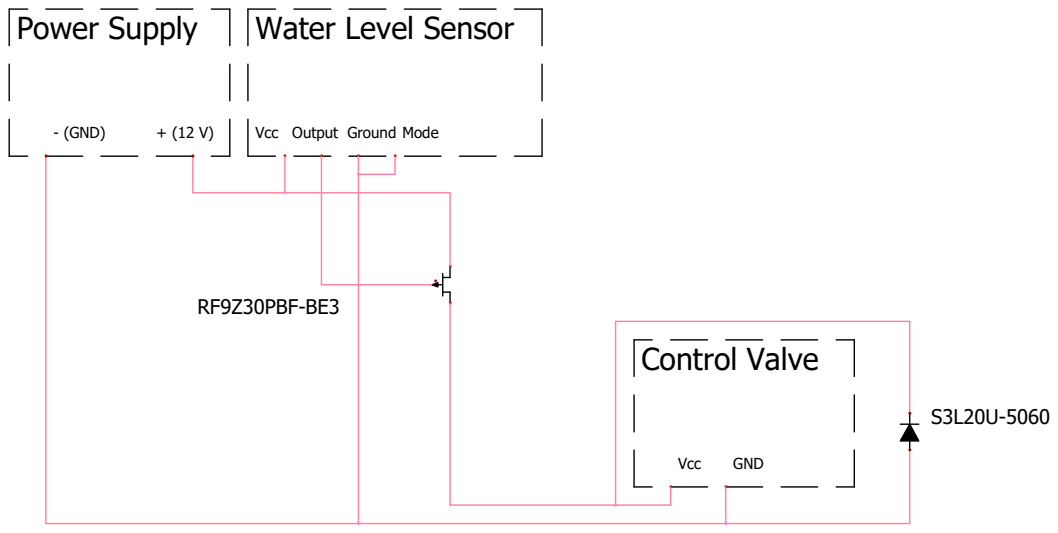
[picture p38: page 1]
SOLIDWORKS Electrical; Power Supply; - (GND); Control Valve; Vcc; GND; RF9Z30PBF-BE3

Water Level Sensor

Vcc Output Ground Mode

Control | REVISION 0 SCHEME

0 | | mpbea10/29/2023
DATEREV. | NAME | CHANGES
User data 1 | User data 2

CONTRACT: | Main electrical closet LOCATION: | 05 L1

Document realized with version :
SOLIDWORKS Educational Product. For Instructional Use Only.

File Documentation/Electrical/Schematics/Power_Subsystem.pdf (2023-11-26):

- +12 DC

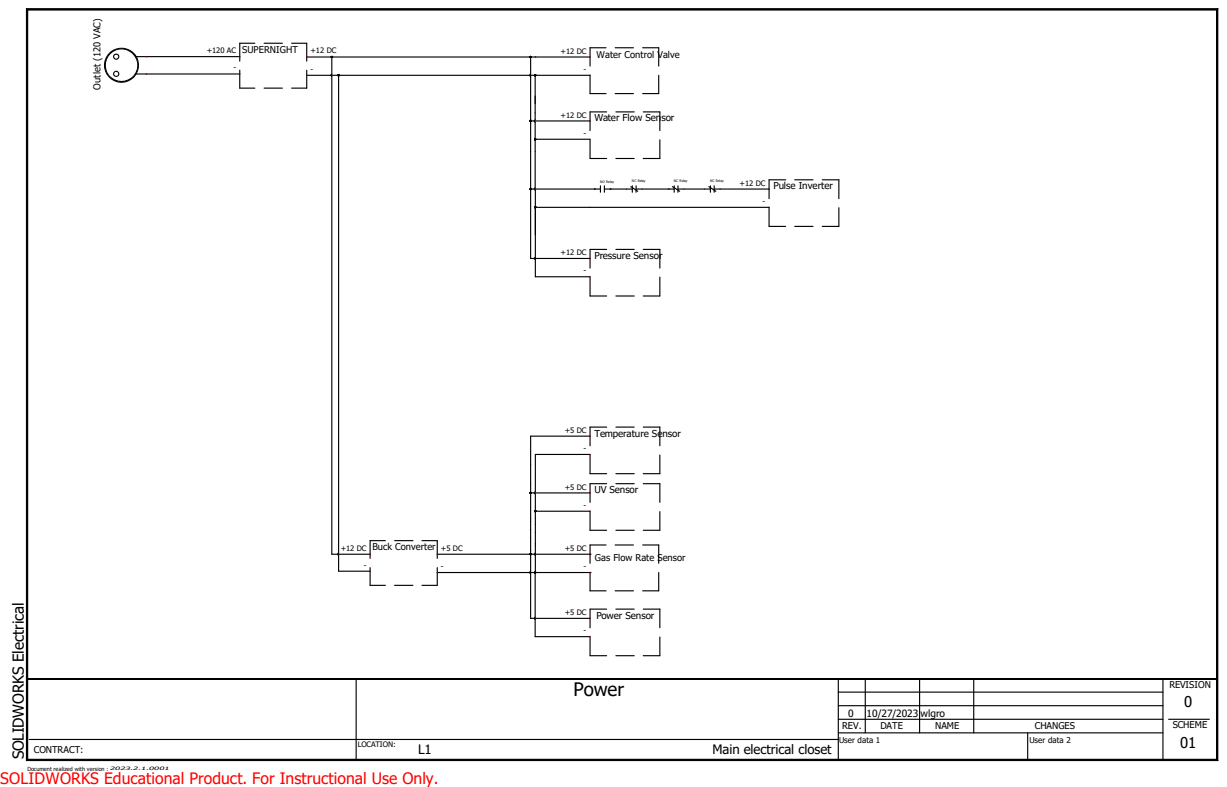
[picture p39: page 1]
wlgro 10/27/2023 SOLIDWORKS Electrical; Outlet (120 VAC⁾; Water Control Valve; SUPERNIGHT; Buck Converter -; NO Relay; NC Relay

Water Flow Sensor

Pulse Inverter ⁺¹² DC

Pressure Sensor ⁺¹² DC
- Temperature Sensor ⁺⁵ DC

- UV Sensor ⁺⁵ DC

Power Sensor ⁺⁵ DC
Gas Flow Rate Sensor

Power | | REVISION 0 SCHEME

REV. | DATE | NAME | CHANGES

2023.2.1.0001 | Main electrical closet | 01 L1
User data 1 | User data 2

LOCATION: Document realized with version : CONTRACT:
SOLIDWORKS Educational Product. For Instructional Use Only.

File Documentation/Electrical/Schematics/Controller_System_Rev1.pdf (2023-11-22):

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

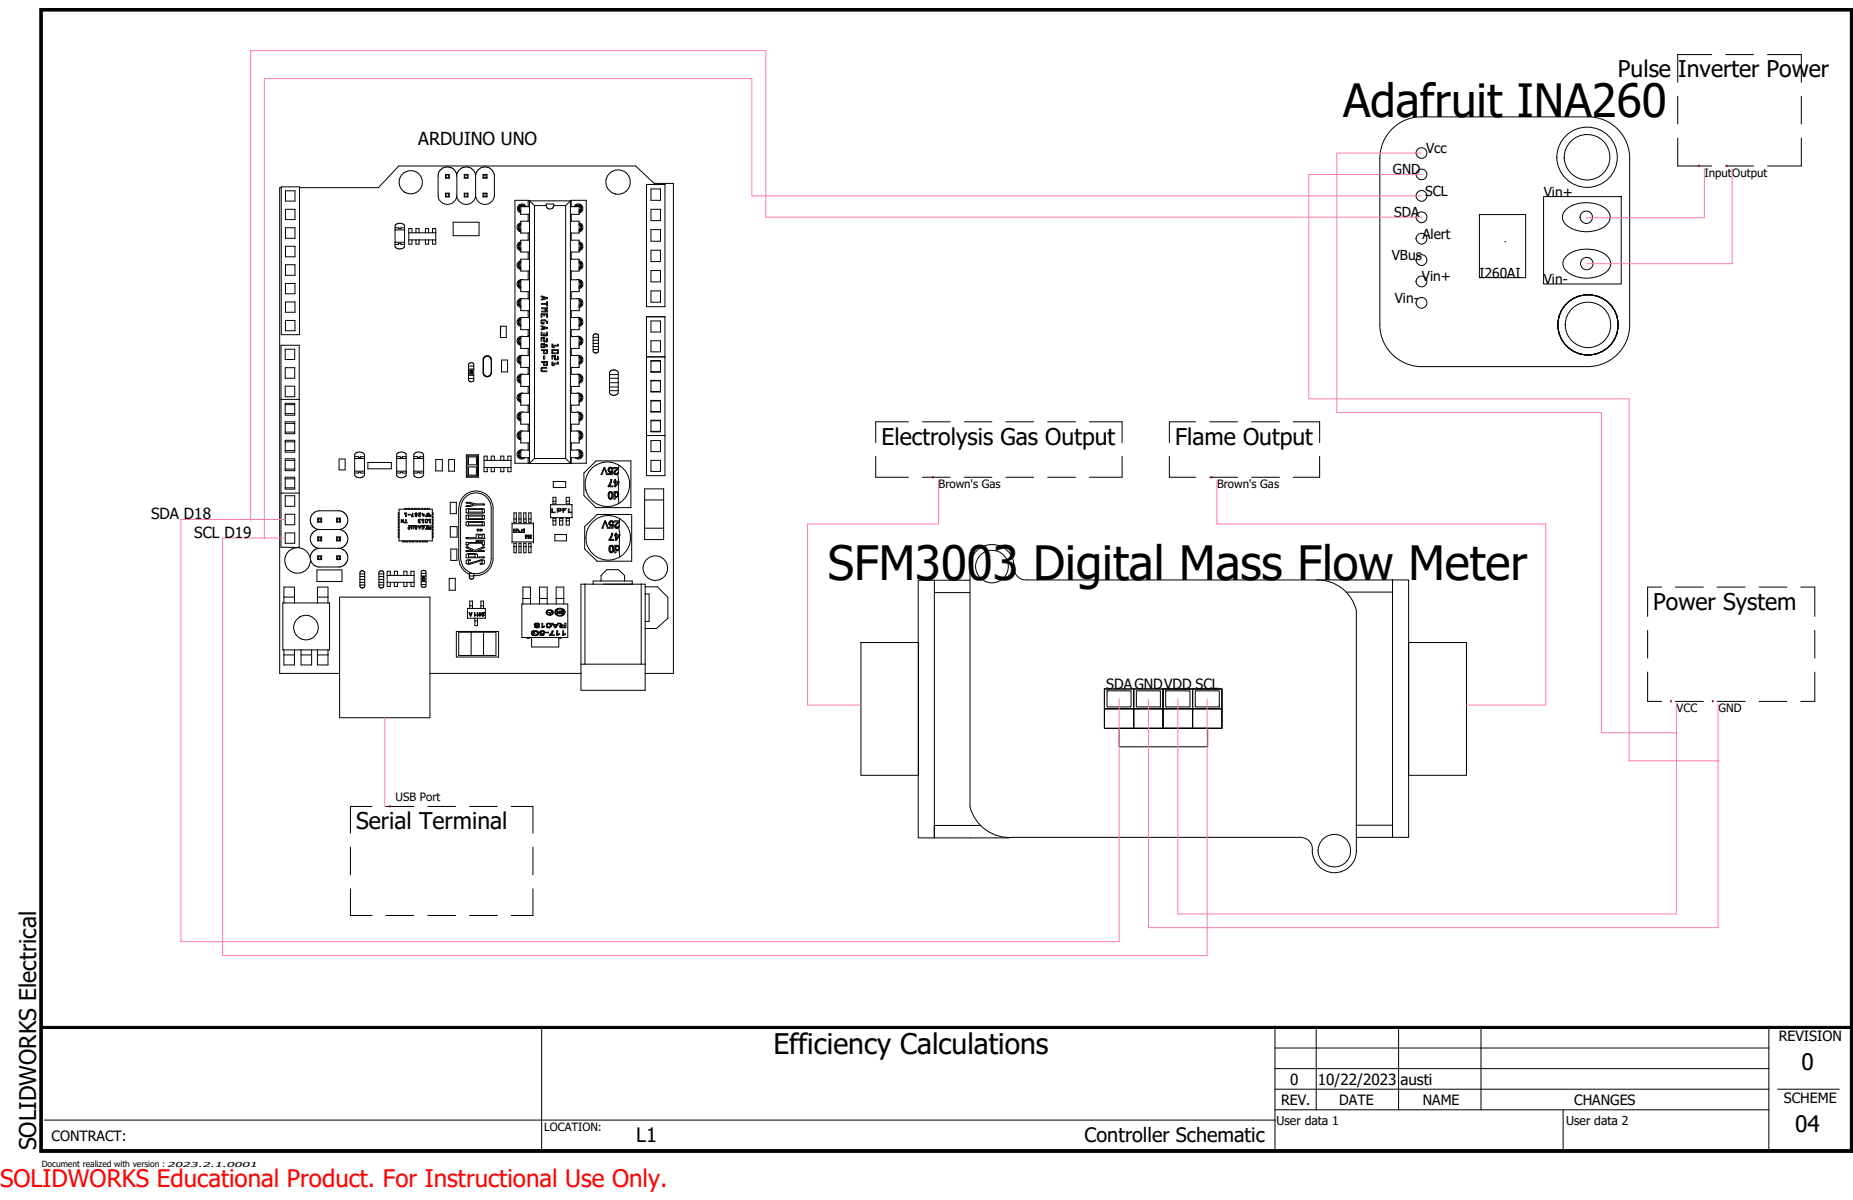
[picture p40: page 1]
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

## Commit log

2023-11-02 Update Electrolysis_System.md
    Corrected writing errors
    Changed the selected rectifier component to one that has higher current capacity and also is more convenient to use.
2023-11-06 Add files via upload
    Added image of electrolysis system buildable schematic
2023-11-30 Delete Documentation/Electrical/Schematics/Sources/water-system.SLDDRW
    wrong file
    [water-system.SLDDRW]
